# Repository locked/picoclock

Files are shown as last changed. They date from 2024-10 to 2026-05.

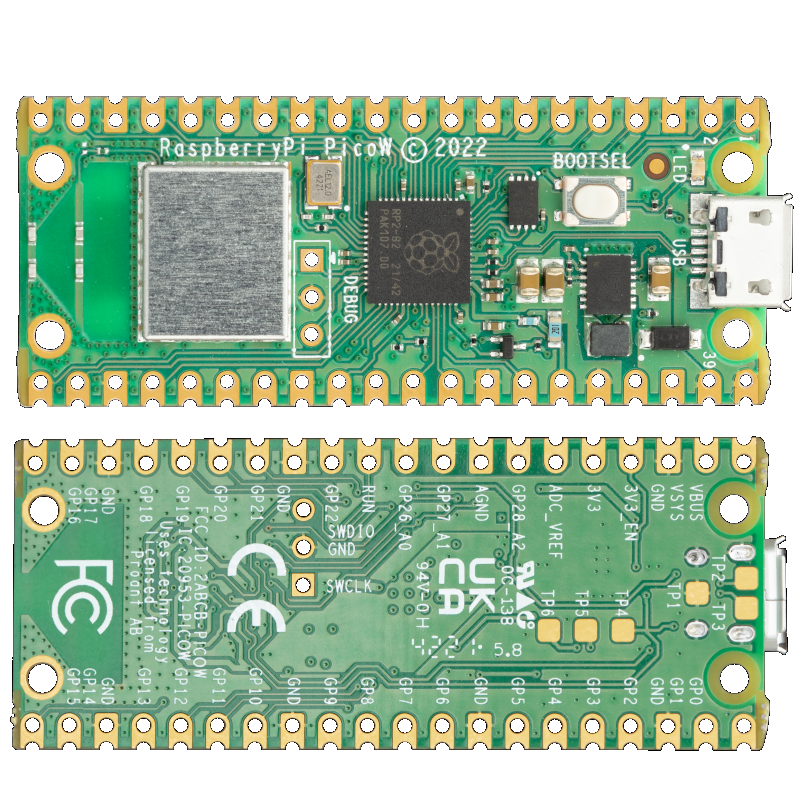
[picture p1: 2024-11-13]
pcb-mini/CYW43439/datasheets/raspberry-pi-pico-w.jpg

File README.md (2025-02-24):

# RP2040 based Alarm Clock

## Presentation

This repo is an attempt at building a Pico based alarm clock. It was created for my kids and features:

- date/time (obviously)
- alarm (plays wav file on sdcard)
- weather (current and forecast)
- epaper screen
- 3d printable case

The configuration is done remotely, and the clock synchronize from time to time (it can be forced too). The time is also fetched from a remote server.

## Repository Architecture

- **3d**: contains printable models for the case, buttons
- **fw**: the firmware, based on a lightweight "rtos"
- **pcb**: the PCBs:
  - the main PCB receiving the RP2040 board
  - the front PCB with the backlight leds
- **api**: remote api basic php script

## Pictures

case

## Build

```
mkdir build
cd build
cmake -DCMAKE_BUILD_TYPE=Debug ..
make
```

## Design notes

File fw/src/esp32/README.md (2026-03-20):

== building ==

Basic binary files are provided, but the code should be fairly easy to build with:

 arduino-cli compile -b esp32:esp32:esp32 --verbose

Then copy the binary from the build directory, for example:

 cp /home/user/.cache/arduino/sketches/XXX/esp32.ino.bin .

Once you have the 3 bin files (or just want to use the one from this repository), flash your module with esptool (change the `boot_app0.bin` path):

 esptool --chip esp32 --port "/dev/ttyUSB0" --baud 921600  --before default-reset --after hard-reset write-flash  -z --flash-mode keep --flash-freq keep --flash-size keep 0x1000 esp32.ino.bootloader.bin 0x8000 esp32.ino.partitions.bin 0xe000 path/to/esp32/tools/boot_app0.bin 0x10000 esp32.ino.bin

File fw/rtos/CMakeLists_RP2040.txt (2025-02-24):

cmake_minimum_required(VERSION 3.13)

set(CMAKE_VERBOSE_MAKEFILE OFF)
set(CMAKE_COLOR_MAKEFILE ON)
set(PROJECT_NAME picoclock)

set(PICO_BOARD pico_w)

# ==========================
# DEFAULT VARIABLES OPTIONS
# ==========================
if(NOT OST_BUNDLE)
    set(OST_BUNDLE "RASPI_PICO")
endif()

if(NOT PICO_SDK_PATH)
    set(PICO_SDK_PATH "../pico-sdk")
endif()

if(NOT CMAKE_BUILD_TYPE)
    set(CMAKE_BUILD_TYPE Release)
endif()

# ==========================
# COMMON FILES
# ==========================
set(OST_SRCS
    system/main.c
    system/alarms.c
    system/utils.c
    system/sdcard.c
    system/ff_diskio_sdcard.c
    system/debug.c
    system/filesystem.c
    system/sdcard.c
    system/qor.c
    system/qor_armv6m.s
    system/audio_player.c
    system/ui_task.c
    system/net_task.c
    system/fs_task.c
    system/audio_player.c
    system/ff/ff.c
    system/ff/ffsystem.c
    system/ff/ff_stubs.c
    library/mini_qoi.c
    library/tiny-json.c
    library/mcp9808/mcp9808.c
    library/pcf8563/pcf8563.c
    library/mcp46XX/mcp46XX.c
    library/mcp23009/mcp23009.c
    library/graphics.c
    library/tinyhttp/http.c
    library/tinyhttp/chunk.c
    library/tinyhttp/header.c
    #library/button_debounce.c
    library/flash_storage.c
    library/pico_i2s.c
    library/ini.c
    platform/raspberry-pico-w/wifi.c
    platform/raspberry-pico-w/pwm_sound.c
)
include_directories(
    ${CMAKE_CURRENT_SOURCE_DIR}/src
    ${CMAKE_CURRENT_SOURCE_DIR}/hal
    ${CMAKE_CURRENT_SOURCE_DIR}/include
    ${CMAKE_CURRENT_SOURCE_DIR}/library
    ${CMAKE_CURRENT_SOURCE_DIR}/system/ff
    ${CMAKE_CURRENT_SOURCE_DIR}/system/
    ${CMAKE_CURRENT_SOURCE_DIR}/library/epaper
    ${CMAKE_CURRENT_SOURCE_DIR}/library/epaper/Config
    ${CMAKE_CURRENT_SOURCE_DIR}/library/epaper/GUI
    ${CMAKE_CURRENT_SOURCE_DIR}/library/epaper/e-Paper
    ${CMAKE_CURRENT_SOURCE_DIR}/platform/raspberry-pico-w/
)

message("=============  TARGET: RASPBERRY PICO  =============")

add_definitions(-DOST_USE_FF_LIBRARY)

# initialize the SDK based on PICO_SDK_PATH
# note: this must happen before project()
include(${CMAKE_CURRENT_SOURCE_DIR}/platform/raspberry-pico-w/pico_sdk_import.cmake)

include(${CMAKE_CURRENT_SOURCE_DIR}/platform/raspberry-pico-w/pico_extras_import.cmake)

# add_library(BUNDLE_LIBRARIES INTERFACE)
# target_link_libraries(BUNDLE_LIBRARIES INTERFACE )
project(${PROJECT_NAME} LANGUAGES CXX C ASM)

set(CMAKE_VERBOSE_MAKEFILE OFF)
set(CMAKE_CXX_STANDARD 17)
set(CMAKE_CXX_STANDARD_REQUIRED ON)

# initialize the Raspberry Pi Pico SDK
# after project!
pico_sdk_init()

add_subdirectory(${CMAKE_CURRENT_SOURCE_DIR}/library/epaper/Config)
add_subdirectory(${CMAKE_CURRENT_SOURCE_DIR}/library/epaper/e-Paper)
add_subdirectory(${CMAKE_CURRENT_SOURCE_DIR}/library/epaper/Fonts)
add_subdirectory(${CMAKE_CURRENT_SOURCE_DIR}/library/epaper/GUI)

# ------ Executable
add_executable(${PROJECT_NAME} ${OST_SRCS} ${MIDDLEWARE_SRCS})

# ------ Link
target_link_libraries(${PROJECT_NAME} PUBLIC "-Wl,--start-group"
	gcc m c stdc++ pico_stdlib hardware_spi hardware_dma hardware_pio hardware_i2c hardware_rtc hardware_pwm hardware_exception cmsis_core pico_cyw43_arch_lwip_poll ePaper GUI Fonts Config pico_audio_i2s "-Wl,--end-group")
set_target_properties(${PROJECT_NAME} PROPERTIES OUTPUT_NAME "${PROJECT_NAME}")

pico_add_extra_outputs(${PROJECT_NAME})

pico_generate_pio_header(${PROJECT_NAME} ${CMAKE_CURRENT_LIST_DIR}/library/pico_i2s.pio)
#pico_generate_pio_header(${PROJECT_NAME} ${CMAKE_CURRENT_LIST_DIR}/library/button_debounce.pio)

pico_enable_stdio_usb(${PROJECT_NAME} 1)
pico_enable_stdio_uart(${PROJECT_NAME} 1)

target_compile_definitions(${PROJECT_NAME} PRIVATE
    WIFI_SSID=\"${WIFI_SSID}\"
    WIFI_PASSWORD=\"${WIFI_PASSWORD}\"
    SERVER_IP=\"${SERVER_IP}\"
    SERVER_PORT=\"${SERVER_PORT}\"
    PICO_AUDIO_I2S_MONO_INPUT=1
	#PICO_AUDIO_I2S_DATA_PIN=16
	#PICO_AUDIO_I2S_CLOCK_PIN_BASE=17
)

# ==========================
# CUSTOM TARGETS
# ==========================
add_custom_target(RaspberryPico
    COMMAND ${CMAKE_COMMAND}
    -DOST_BUNDLE=RASPI_PICO
    -DPICO_SDK_PATH=../pico-sdk
    -DPICO_BOARD=pico_w
    -DCMAKE_BUILD_TYPE=Debug
    -B "${CMAKE_CURRENT_BINARY_DIR}/RaspberryPico"
    -S "${CMAKE_SOURCE_DIR}"
    COMMAND ${CMAKE_COMMAND} --build "${CMAKE_CURRENT_BINARY_DIR}/RaspberryPico"
)

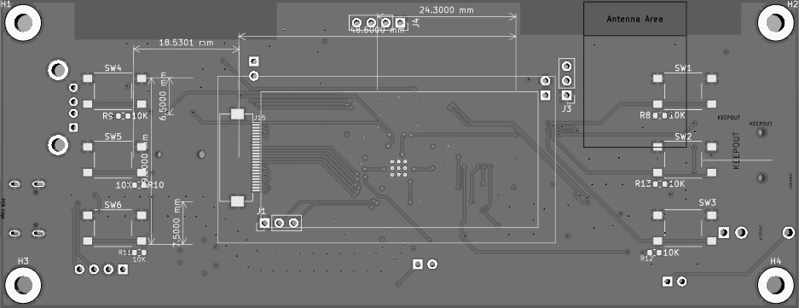
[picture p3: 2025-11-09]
3d-mini/picoclock.png

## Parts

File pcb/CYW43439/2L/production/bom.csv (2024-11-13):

Designator | Footprint | Quantity | Value | LCSC Part #
C1, C2 | 0603 | 2 | 18p | C1647
C10, C12, C7, C9 | 0603 | 4 | 1u | C15849
C11, C6, C8 | 0603 | 3 | 100n | C14663
C13, C14 | 0603 | 2 | 2.2u | C23630
C15, C16, C5 | 0603 | 3 | 4.7u | C19666
C17 | 0402 | 1 | 0.3p | C880415
C18 | 0402 | 1 | 0.36p
C19, C20 | 0402 | 2 | 0.2p | C2836760
C3, C4 | 0603 | 2 | 10p | C1634
FB1, FB2 | 0603 | 2 | 600@100MHz
J1 | PinHeader_1x03_P2.54mm_Vertical | 1 | GPIOs
J2 | PinHeader_1x04_P2.54mm_Vertical | 1 | SPI
J3 | PinHeader_1x02_P2.54mm_Vertical | 1 | Power
L1 | 0603 | 1 | 4.7n | C1030
L2 | 0603 | 1 | 2.2uH
R1 | 0603 | 1 | 220 | C22962
R2 | 0603 | 1 | 0
R3, R6 | 0603 | 2 | 10K | C25804
R4 | 0603 | 1 | 470 | C23179
R5 | 0603 | 1 | 22 | C23345
U1 | BGA63N40P7X12_287X487X55N | 1 | CYW43439KUBGT | C5359496
Y1 | Crystal_SMD_2016-4Pin_2.0x1.6mm | 1 | Crystal | C2901740

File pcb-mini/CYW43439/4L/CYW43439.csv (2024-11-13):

Id | Designator | Footprint | Quantity | Designation | Supplier and ref
1 | C13,C14 | C_0603_1608Metric | 2 | 2.2u
2 | C3,C4 | C_0603_1608Metric | 2 | 10p
3 | C20,C19 | C_0402_1005Metric | 2 | 0.2p
4 | J3 | PinHeader_1x02_P2.54mm_Vertical | 1 | Power
5 | FB1,FB2 | L_0603_1608Metric | 2 | 600@100MHz
6 | C6,C11,C8 | C_0603_1608Metric | 3 | 100n
7 | R6,R3 | R_0603_1608Metric | 2 | 10K
8 | C16,C15,C5 | C_0603_1608Metric | 3 | 4.7u
9 | C2,C1 | C_0603_1608Metric | 2 | 18p
10 | J2 | PinHeader_1x04_P2.54mm_Vertical | 1 | SPI
11 | L1 | L_0603_1608Metric | 1 | 4.7n
12 | C10,C12,C9,C7 | C_0603_1608Metric | 4 | 1u
13 | Y1 | Crystal_SMD_2016-4Pin_2.0x1.6mm | 1 | Crystal
14 | J1 | PinHeader_1x03_P2.54mm_Vertical | 1 | GPIOs
15 | R2 | R_0603_1608Metric | 1 | 0
16 | L2 | L_0603_1608Metric | 1 | 2.2u
17 | C17 | C_0402_1005Metric | 1 | 0.3p
18 | U1 | BGA63N40P7X12_287X487X55N | 1 | CYW43439KUBGT
19 | C18 | C_0402_1005Metric | 1 | 0.36p
20 | R4 | R_0603_1608Metric | 1 | 470
21 | R5 | R_0603_1608Metric | 1 | 22
22 | R1 | R_0603_1608Metric | 1 | 220

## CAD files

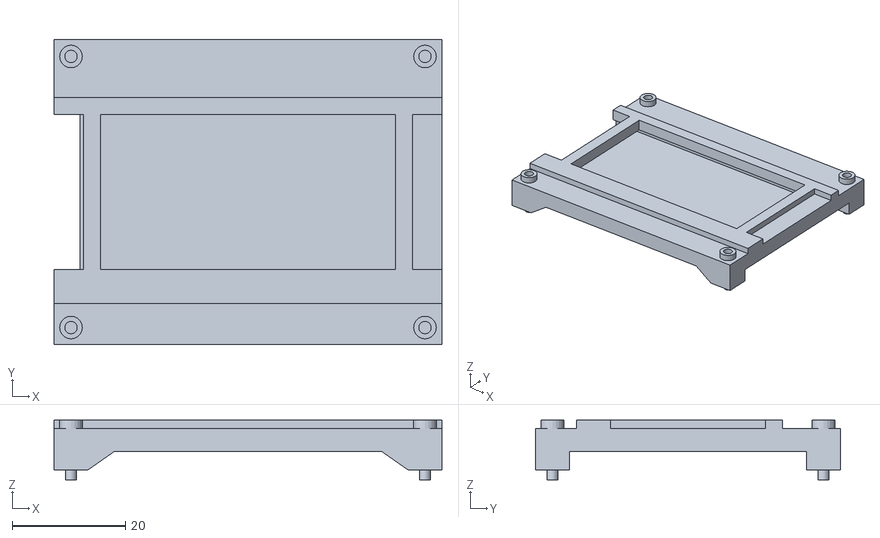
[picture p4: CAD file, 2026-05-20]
3d-mini/prod/v13/screen_holder-3.stl
68.4 x 53.8 x 10.5

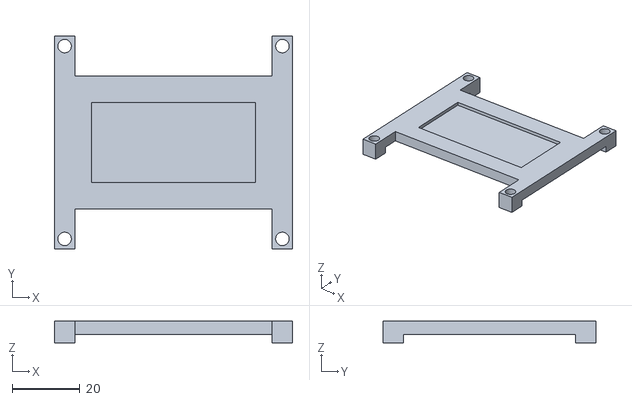
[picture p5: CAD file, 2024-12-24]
3d/front-v1/front.stl
70.4 x 63.0 x 6.50

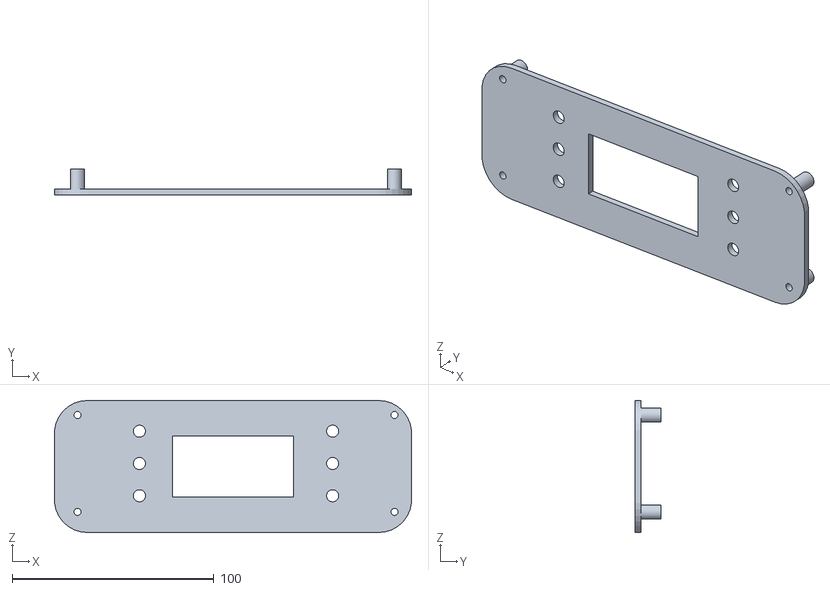
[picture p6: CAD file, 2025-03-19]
3d/panel-v1/panel.stl
176.8 x 13.0 x 65.4

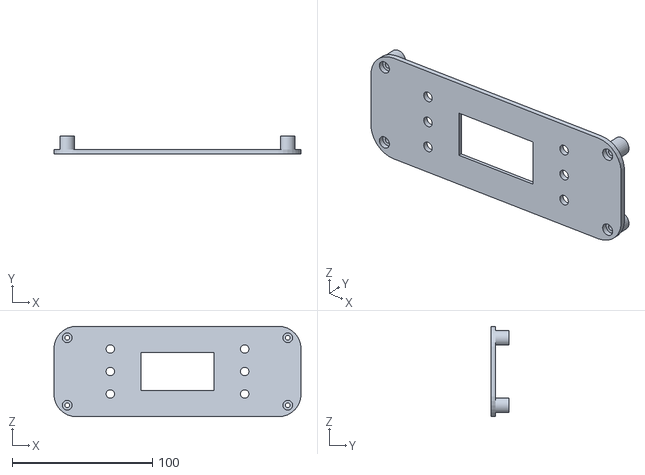
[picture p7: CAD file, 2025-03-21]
3d/panel.stl
175.8 x 12.5 x 64.4

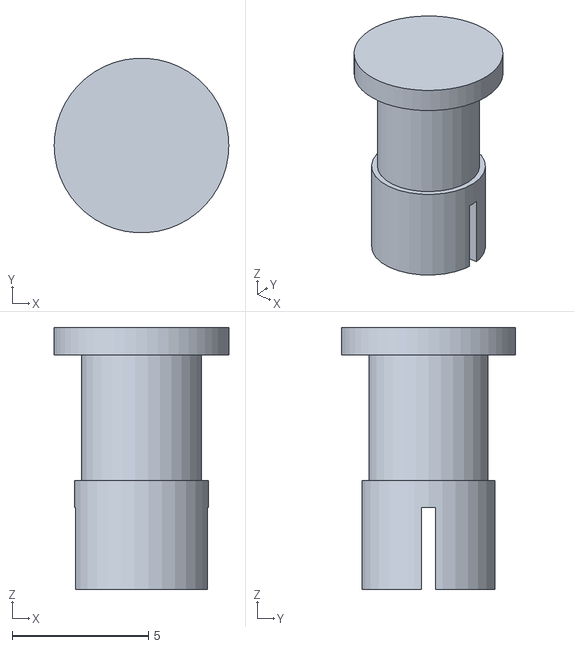
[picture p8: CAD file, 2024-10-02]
3d/prod1/button-2.4.stl
6.40 x 6.39 x 9.60

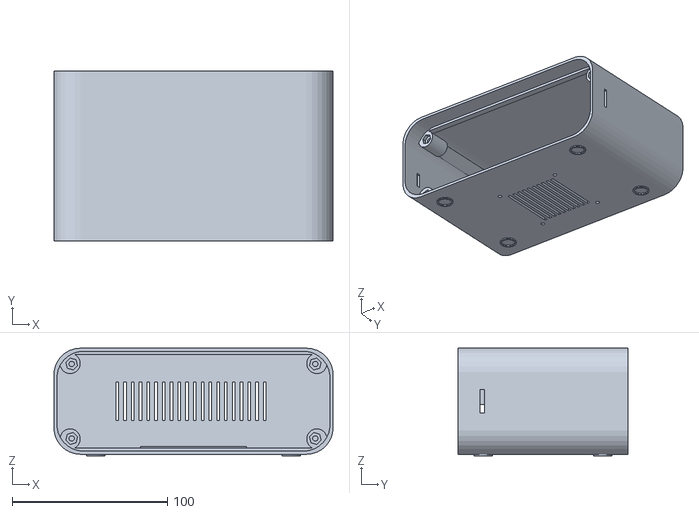
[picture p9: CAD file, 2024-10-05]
3d/prod2/case.stl
179.8 x 109.8 x 69.4

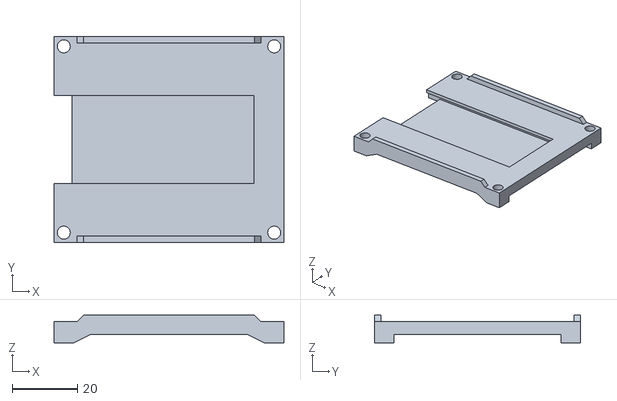
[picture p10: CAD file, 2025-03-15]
3d/front.stl
70.4 x 63.0 x 8.50

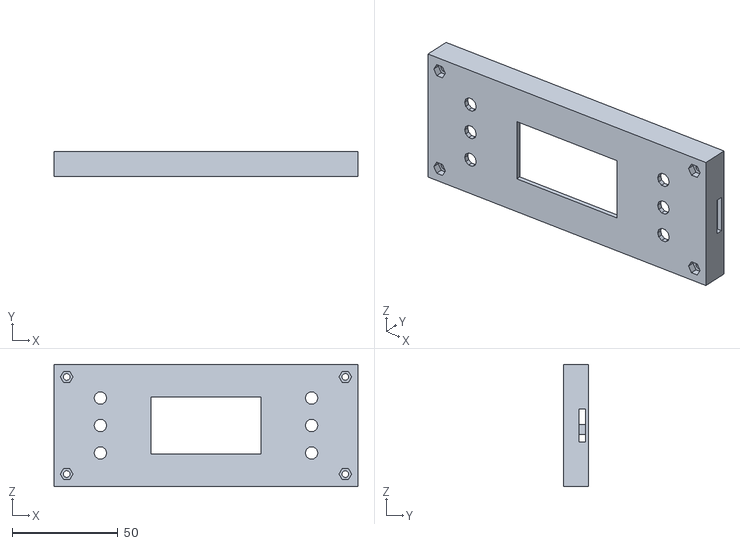
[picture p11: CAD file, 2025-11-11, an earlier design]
3d-mini/prod/v1/case-front.stl
144.0 x 12.0 x 58.0

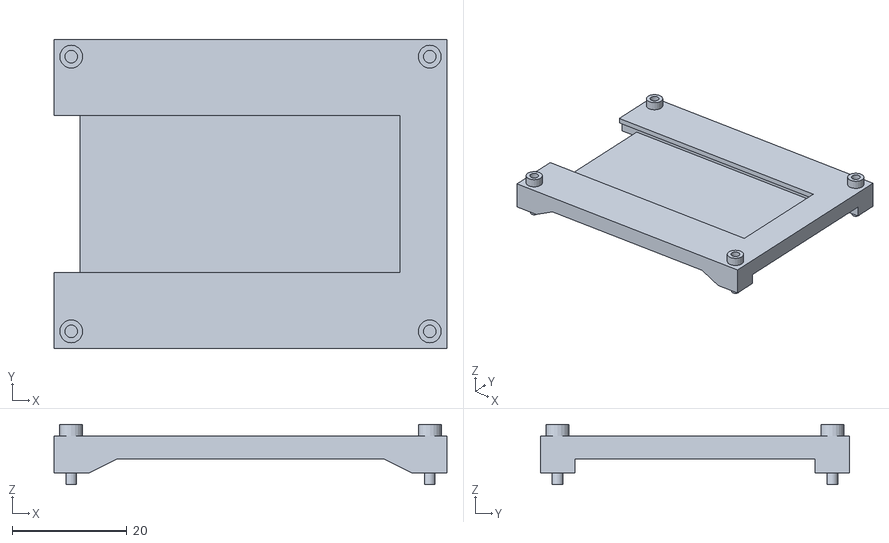
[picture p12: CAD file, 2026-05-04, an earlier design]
3d-mini/prod/v10/screen_holder.stl
68.4 x 53.8 x 10.5

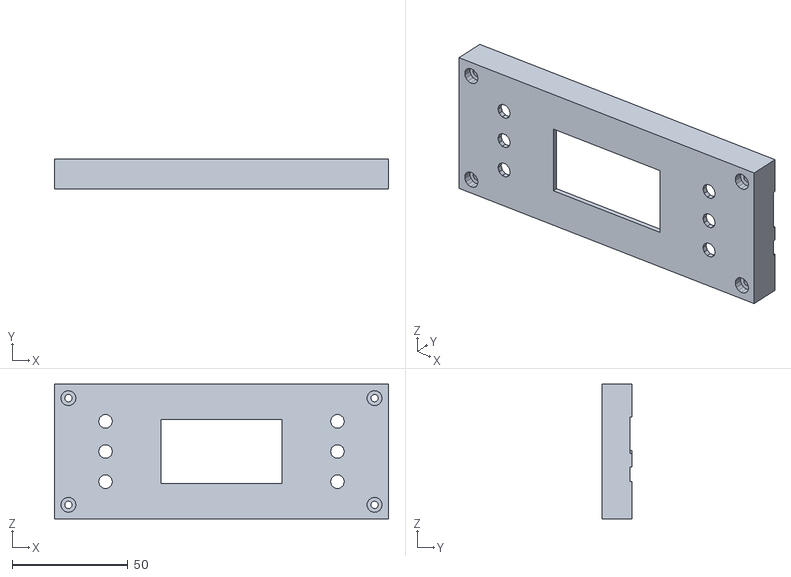
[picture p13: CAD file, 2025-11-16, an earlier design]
3d-mini/prod/v2/case-front.stl
144.0 x 13.0 x 58.0

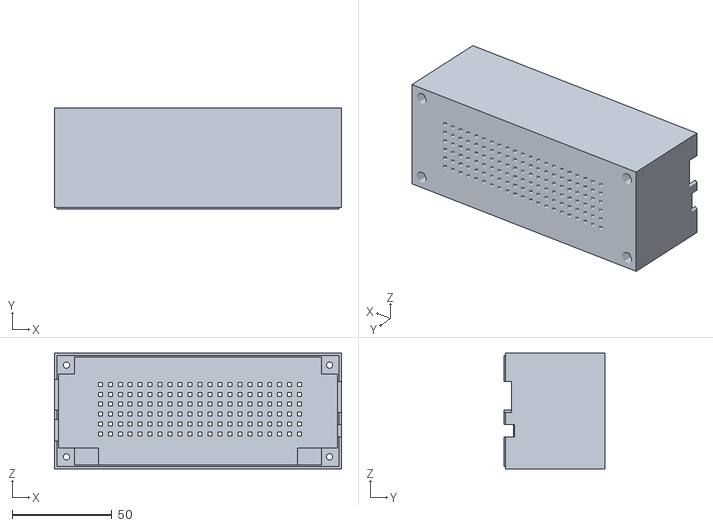
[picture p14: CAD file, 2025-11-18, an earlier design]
3d-mini/prod/v3/case-back.stl
144.0 x 50.8 x 58.0

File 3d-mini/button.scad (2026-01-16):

include <common.scad>;

hole_diam = 5.4;
outer_diam = 6;   // pcb holes are 5mm
inner_diam = 5;   // pcb holes are 5mm
depth = 6 + 1.6 + 1;
depth_blocker = 5.5 - 2.3;
depth_visible = 3.8;
sphere_visible = 0.4;

//btn_size = 2.4;	// Ok, tight
btn_size = 2.5;	// Ok, loose
btn = [btn_size, btn_size, 3];
fente = [1.4, 0.5, 3];

module body() {
    // part on btn
    cylinder(h=depth_blocker, d=inner_diam, $fn=30);
    // blocker
    translate([0, 0, depth_blocker-1]) cylinder(h=1, d=outer_diam+2, $fn=50);
    // visible part
    minkowski()
    {
        translate([0, 0, depth_blocker]) cylinder(h=depth_visible-sphere_visible, d=hole_diam-0.4-sphere_visible*2, $fn=40);
        sphere(sphere_visible);
    }
}

difference() {
    body();

    shiftx = 0.1;

    translate([0-shiftx, 0, btn[2]/2]) cube(btn, center=true);
    translate([-btn[0]/2-fente[0]/2-shiftx, 0, fente[2]/2]) cube(fente, center=true);
    translate([+btn[0]/2+fente[0]/2-shiftx, 0, fente[2]/2]) cube(fente, center=true);
}

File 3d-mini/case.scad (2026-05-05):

include <common.scad>;
include <screen_holder.scad>;

support_large_speaker = true;

module pcb() {
    rotate([90]) translate([t, t]) difference() {
        cube(pcb);
        for (x = [0:1]) {
            for (y = [0:1]) {
                translate([pcb_screw_pos[0] + x * (pcb[0]-pcb_screw_pos[0]*2), pcb_screw_pos[0] + y * (pcb[1]-pcb_screw_pos[1]*2)]) cylinder(pcb[2], pcb_screw_diam/2, pcb_screw_diam/2, $fn=15);
            }
        }

        // Pins holes
        for (x = [0:1]) {
            for (y = [0:1]) {
                cyl_x = (x == 0 ? 1 : -1) * screen_holder_in[0]/2 + (x == 0 ? -1 : 1) * screen_holder_out[0]/2;
                cyl_y = (y == 0 ? 1 : -1) * screen_holder_out[1]/2 + (y == 0 ? -1 : 1) * screen_holder_screw_rad + (y == 0 ? -1 : 1) * 1;
                echo(cyl_x, cyl_y);
                translate([
                    cyl_x - t,
                    cyl_y - t,
                    -15])
                translate([front[0]/2, front[1]/2, front[2]+2.7])
                cylinder(h=3, d=2.5, $fn=20);
            }
        }
    }

    rotate([90]) io();
}

module front_screw() {
    // PCB support screw
    for (x = [0:1]) {
        for (y = [0:1]) {
            translate([
                (x == 0 ? pcb[0] - pcb_screw_pos[0] : pcb_screw_pos[0]) + t,
                (y == 0 ? pcb[1] - pcb_screw_pos[1] : pcb_screw_pos[1]) + t,
                0
            ]) cylinder(front[2], pcb_screw_diam/2, pcb_screw_diam/2, $fn=15);

            translate([
                (x == 0 ? pcb[0] - pcb_screw_pos[0] : pcb_screw_pos[0]) + t,
                (y == 0 ? pcb[1] - pcb_screw_pos[1] : pcb_screw_pos[1]) + t,
                front[2] - pcb_bolt_depth]) cylinder(h=pcb_bolt_depth, r=pcb_bolt_diam/2, $fn=15);
        }
    }
}
module front_joint(joint_width_margin=0, y_adjust=0) {
    for (i = [0:1]) {
        // horizontal
        translate([
            t/2 + joint_margin,
            i * front[1] + (i == 0 ? 1 : -2) * joint_width + (i == 0 ? 1 : -1) * joint_margin + (i == 0 ? 0 : -1) * joint_width_margin,
            -1+joint_margin + y_adjust]) cube([
                front[0]-t-joint_margin*2,
                joint_width+joint_width_margin,
                1-joint_margin
            ]);
    }
    for (i = [0:1]) {
        // vertical
        translate([
            i * front[0] + (i == 0 ? 1 : -2) * joint_width + (i == 0 ? 1 : -1) * joint_margin + (i == 0 ? 0 : -1) * joint_width_margin,
            t/2 + joint_margin,
            -1+joint_margin + y_adjust]) cube([
                joint_width+joint_width_margin,
                front[1]-t-joint_margin*2,
                1-joint_margin
            ]);
    }
}
module back_joint() {
    for (i = [0:1]) {
        translate([
            0,
            i * front[1] + (i == 0 ? 0 : -1) * joint_width + (i == 0 ? 0 : 0) * joint_margin,
            0]) cube([
                front[0],
                joint_width,
                1
            ]);
    }
    for (i = [0:1]) {
        translate([
            i * front[0] + (i == 0 ? 0 : -1) * joint_width + (i == 0 ? 0 : 0) * joint_margin,
            0,
            0]) cube([
                joint_width,
                front[1],
                1
            ]);
    }
}
module front() {
    front_inner = [pcb[0] + pcb_margin, pcb[1] + pcb_margin, front[2] - t];

    rotate([90]) difference() {
        union(){
            cube(front);
            front_joint();
        }
        translate([t-pcb_margin/2, t-pcb_margin/2]) cube(front_inner);
        front_screw();
        screen();
        buttons();
        io();
        borders();
        cornersfront();
        bordersfront();
    }

    // screen holder pins
    rotate([90]) translate([
        front[0]/2,
        front[1]/2,
        front[2]-t
    ]) screen_holder_pins();
    // screen stop pin
    rotate([90]) translate([
        front[0]/2 - screen_holder_out[1]/2 - 8.3,
        16,
        front[2]-t-5])
    cube([3,3,5]);

    // add PCB support (cannot do it earlier
    // since it overlap with main body and
    // difference does not handle that well)
    rotate([90]) difference() {
        for (x = [0:1]) {
            for (y = [0:1]) {
                translate([
                    t + x * (front[0] - pcb_support[0] - t*2) + (x == 1 ? 1 : -1) * pcb_margin / 2,
                    t + y * (front[1] - pcb_support[1] - t*2) + (y == 1 ? 1 : -1) * pcb_margin / 2,
                    pcb[2]]) cube(pcb_support);
            }
        }
        front_screw();
    }
}

module io(forback=false) {
    // usb-c
    translate([
        0,
        front[1]/2 - usbc_pos - usbc[1] / 2,
        -usbc[0],
    ]) cube([usbc[2], usbc[1], usbc[0] + (forback ? 1 : 0)]);

    // usb-a
    translate([
        0,
        front[1]/2 + usba_pos - usba[1] / 2,
        -usba[0],
    ]) cube([usba[2], usba[1], usba[0] + (forback ? 1 : 0)]);

    // SD card
    translate([
        front[0] - sd[2],
        front[1]/2 + sd_pos - sd[1]/2,
        -sd[0],
    ]) cube([sd[2], sd[1], sd[0] + (forback ? 1 : 0)]);

    // Jack
    translate([
        front[0] - jack[2],
        front[1]/2 - jack_pos - jack[1]/2,
        -jack[0],
    ]) cube([jack[2], jack[1], jack[0] + (forback ? 1 : 0)]);
}

module screen() {
    translate([
        front[0]/2 - screen_visible_size[0]/2,
        front[1]/2 - screen_visible_size[1]/2,
        front[2]-t,
    ]) cube([
        screen_visible_size[0],
        screen_visible_size[1],
        screen_visible_size[2]
    ]);
}

module buttons() {
    for (i=[0:6]) {
        x = (i < 3 ? 1 : -1) * button_x;
        y = (i % 3) * button_y - button_y;
        translate([front[0]/2 + x, front[1]/2 + y, front[2] - t]) cylinder(h=t, d=button_radius*2);
    }
}

module screen_holder_pins() {
    // Pins toward PCB
    pin_height = 1.6;
    for (x = [0:1])  {
        for (y = [0:1]) {
            cyl_x = (x == 0 ? 1 : -1) * screen_holder_in[0]/2 + (x == 0 ? -1 : 1) * screen_holder_out[0]/2;
            cyl_y = (y == 0 ? 1 : -1) * screen_holder_out[1]/2 + (y == 0 ? -1 : 1) * screen_holder_screw_rad + (y == 0 ? -1 : 1) * 1;
            //echo(cyl_x, cyl_y);
            translate([
                cyl_x,
                cyl_y,
                -pin_height])
            cylinder(h=pin_height, d1=1.8, d2=2, $fn=20);
        }
    }
}



module inserts_holes() {
    // inserts
    for (x = [0:1]) {
        for (y = [0:1]) {
            translate([
                (x == 0 ? pcb[0] - pcb_screw_pos[0] : pcb_screw_pos[0]) + t,
                (y == 0 ? pcb[1] - pcb_screw_pos[1] : pcb_screw_pos[1]) + t,
                -30-5+0.8])
            cylinder(h=30, r=pcb_screw_diam/2+0.1, $fn=15);

            translate([
                (x == 0 ? pcb[0] - pcb_screw_pos[0] : pcb_screw_pos[0]) + t,
                (y == 0 ? pcb[1] - pcb_screw_pos[1] : pcb_screw_pos[1]) + t,
                -5+0.8])
            cylinder(h=5, r=2.5, $fn=15);
        }
    }
}
module back_screw() {
    // PCB support screw
    for (x = [0:1]) {
        for (y = [0:1]) {
            translate([
                (x == 0 ? pcb[0] - pcb_screw_pos[0] : pcb_screw_pos[0]) + t,
                (y == 0 ? pcb[1] - pcb_screw_pos[1] : pcb_screw_pos[1]) + t,
                -back[2]-t])
            cylinder(h=back[2]+t+1, r=pcb_screw_diam/2, $fn=15);

            // bolt
            translate([
                (x == 0 ? pcb[0] - pcb_screw_pos[0] : pcb_screw_pos[0]) + t,
                (y == 0 ? pcb[1] - pcb_screw_pos[1] : pcb_screw_pos[1]) + t,
                -back[2] - pcb_bolt_depth])
            cylinder(h=pcb_bolt_back_depth, r=pcb_bolt_diam/2, $fn=6);
        }
    }
}
module speaker2_holes() {
    for (x = [0:1]) {
        for (y = [0:1]) {
            translate([
                (x == 0 ? -1 : 1) * speaker2_screw_from_center,
                (y == 0 ? -1 : 1) * speaker2_screw_from_center,
                -t-speaker2_support[2]
            ]) cylinder(h=10, r=1.6, $fn=10);
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

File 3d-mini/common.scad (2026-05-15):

// PCB size
pcb = [140, 54, 1.6];
pcb_screw_diam = 3.6;
pcb_screw_pos = [4, 4];
pcb_bolt_diam = 6.5;
pcb_bolt_depth = 3.2;
pcb_bolt_length = 30;
pcb_image = "picoclock_scaled.png";
pcb_margin = 0.4;

// general thickness
t = 1.5;

front = [pcb[0] + t * 2, pcb[1] + t * 2, 12];
back = [pcb[0] + t * 2, pcb[1] + t * 2, 60];
pcb_bolt_back_depth = back[2] - pcb_bolt_length + t + pcb_bolt_depth + front[2];

pcb_support = [pcb_screw_pos[0]*2+pcb_margin/2, pcb_screw_pos[0]*2+pcb_margin/2, front[2] - pcb[2] - t];

joint_margin = 0.2;
joint_width = t/2 - joint_margin;

screen_size = [59.3, 29.6, 1.5];
screen_visible_size = [52, 27.4, 3];

button_x = 50;
button_y = 13;
button_radius = 3;

usbc = [3, 10.7, 10.3];
usba = [6, 15.5, 16.3];
sd = [1.6, 15.7, 19.7];
jack = [4.5, 6.3, 14];
usbc_pos = 9.6;  // from center
usba_pos = 8.14; // from center
sd_pos = 7;
jack_pos = 9.85;

speaker_plate = [132, 10, 19];
speaker = [100, 36, 28];
speaker_support = [11, pcb_support[1], 22];

speaker2 = [51.5, 19.5, 30.3];
speaker2_baffle_diam = 47;
speaker2_screw_diam = 60;
speaker2_screw_from_center = speaker2_screw_diam / 2 * sqrt(2) / 2;
speaker2_support = [52, 52, 2];

screen_holder_screw_rad = 2;
screen_holder_out = [screen_holder_screw_rad*3, pcb[1] - 0.2, 3.5];
//screen_holder_in = [70.4, 39.2, 4];
screen_holder_in = [68.4, 39.2, 4];
screen_size_toborder = 7.1;


// pin position:
// 32.2 / 24
// center: 144 / 2, 58 / 2
// => 72 +/- 31.2 => 40.8 / 103.2
// => 29 +- 24 => 5 / 53
// +80:
// 120.8 / 183.2
// 85 / 133

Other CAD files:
3d-mini/prod/v13/screen_holder.stl
3d/button.stl
3d/prod1/button-2.5.stl
3d/prod1/case_v2.stl
3d/prod1/button-2.3.stl
3d-mini/prod/v11/screen_holder.stl
3d-mini/prod/v12/screen_holder.stl
3d-mini/button_shortbase.scad
3d-mini/prod/v1/case-pcb.stl
3d-mini/prod/v1/case-screenholder.stl
3d-mini/prod/v10/button_shortbase.stl
3d-mini/prod/v10/case-front.stl
3d-mini/prod/v10/case.stl
3d-mini/prod/v11/case-back.stl
3d-mini/prod/v2/case-back.stl
3d-mini/prod/v2/case-screenholder.stl
3d-mini/prod/v2/pcb.stl
3d-mini/prod/v3/case-front.stl
3d-mini/prod/v3/pcb.stl
3d-mini/prod/v3/screenholder.stl
3d-mini/prod/v4/case-back.stl
3d-mini/prod/v5/case-back.stl
3d-mini/prod/v5/case-front.stl
3d-mini/prod/v6/case-back.stl
3d-mini/prod/v6/case-front.stl
3d-mini/prod/v7/button.stl
3d-mini/prod/v7/case-back.stl
3d-mini/prod/v7/case-front.stl
3d-mini/prod/v8/case-back.stl
3d-mini/prod/v9/button.stl
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

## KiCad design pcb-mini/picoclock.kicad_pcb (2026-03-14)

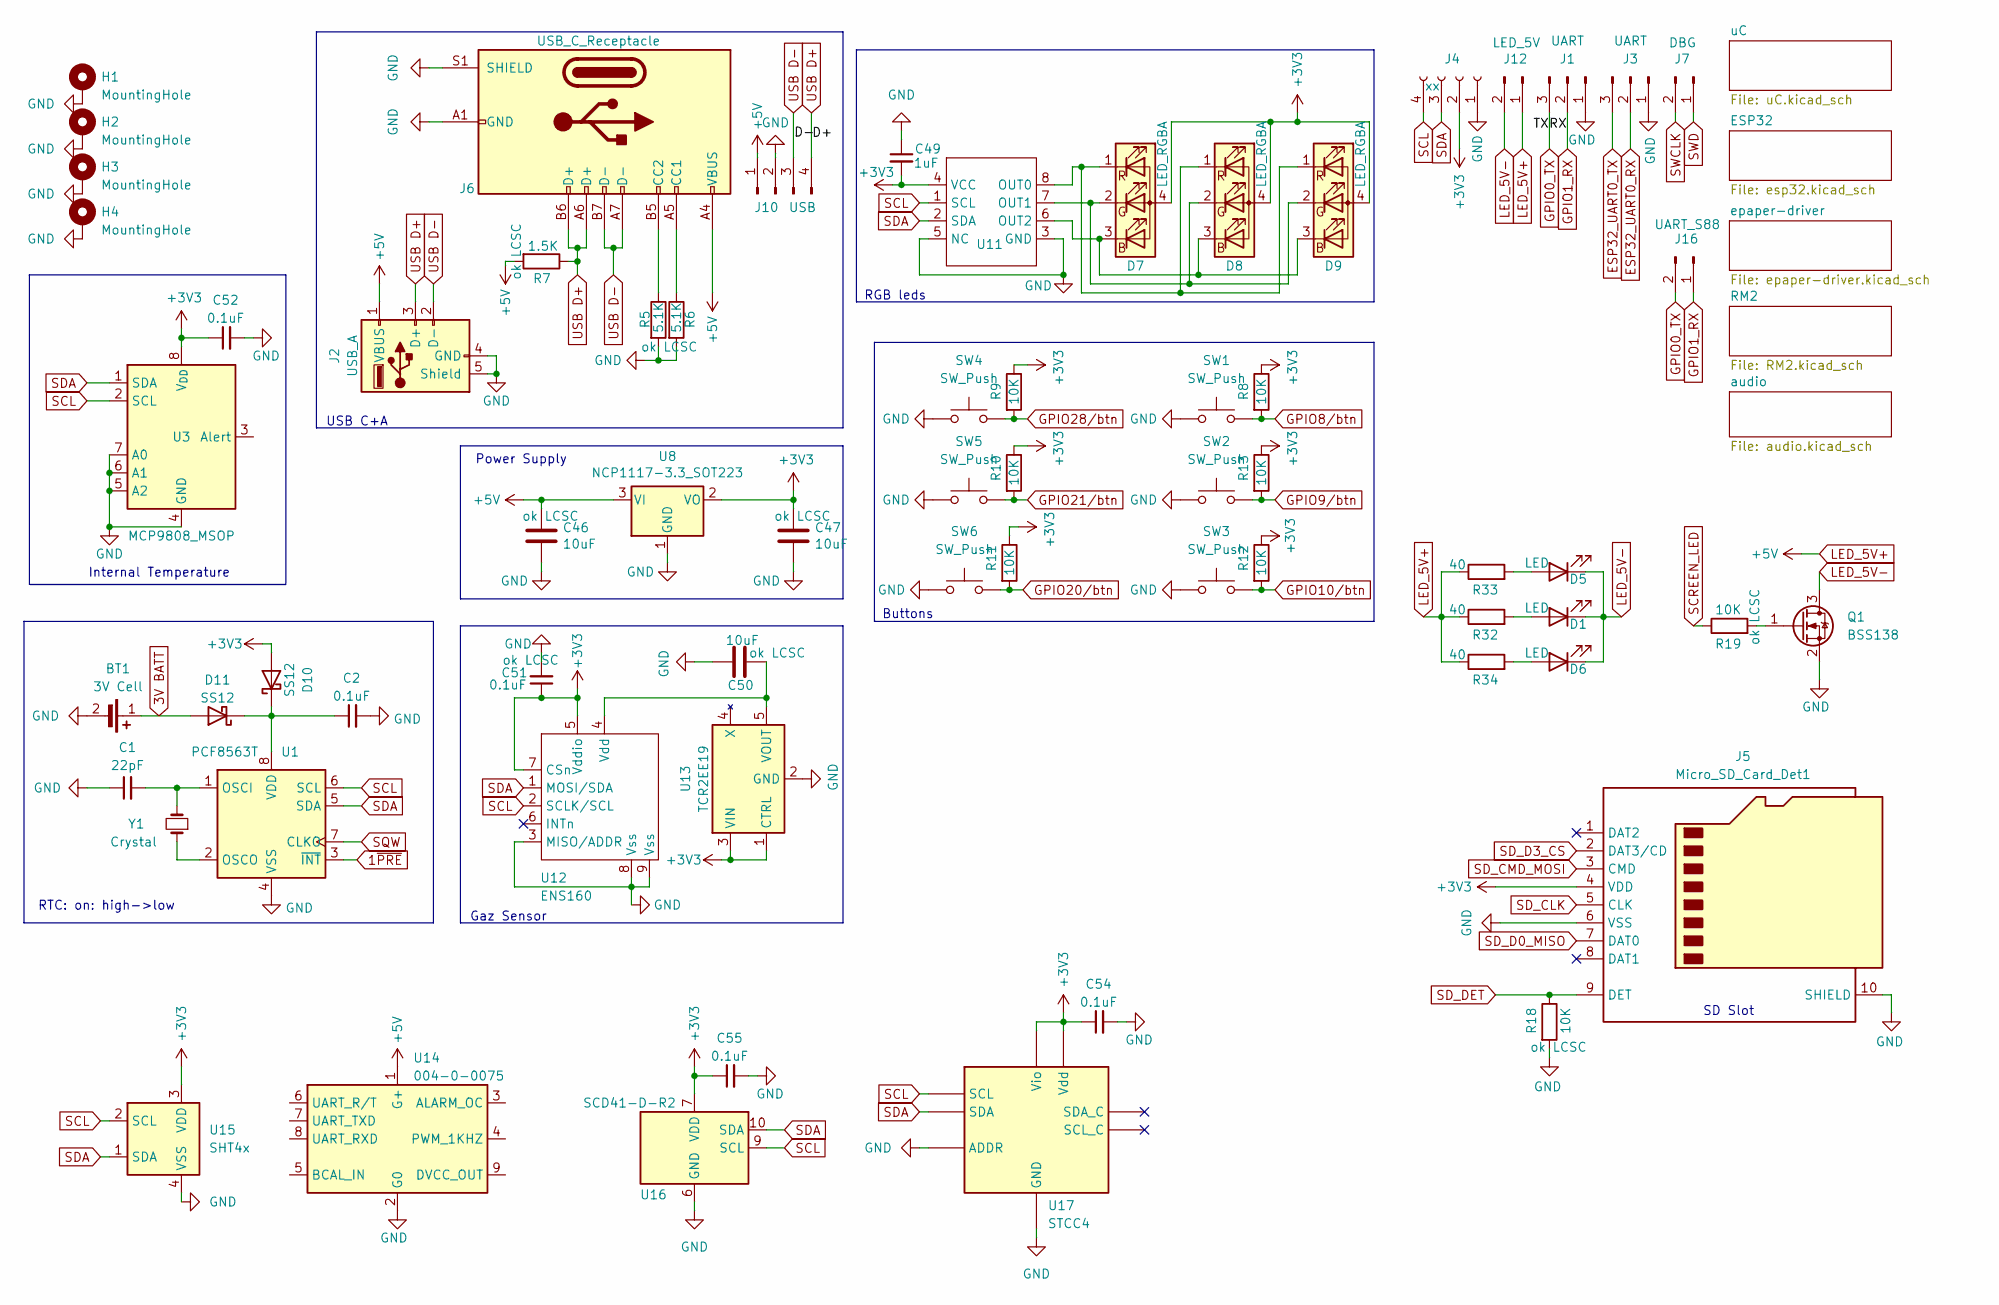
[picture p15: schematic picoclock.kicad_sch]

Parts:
BT1: 3V Cell; MPD_BC501SM-TR
C1: 22pF; C_0603_1608Metric; LCSC C1653
C2, C51, C52, C54, C55: 0.1uF; C_0603_1608Metric; LCSC C14663
C46, C47, C50: 10uF; C_0805_2012Metric; LCSC C15850
C49: 1uF; C_0603_1608Metric
D1, D5, D6: LED; LED_PLCC_2835
D7, D8, D9: LED_RGBA; LED_LiteOn_LTST-C19HE1WT
D10, D11: SS12; D_SOD-323
H1, H2, H3, H4: MountingHole; MountingHole_3.2mm_M3_Pad
J1, J3: UART; PinHeader_1x03_P2.54mm_Vertical
J2: USB_A; USB_A_Connfly_DS1095
J4: xx; PinSocket_1x04_P2.54mm_Vertical
J5: Micro_SD_Card_Det1; microSD_HC_Hirose_DM3AT-SF-PEJM5_combined_MSD-4-A
J6: USB_C_Receptacle; USB_C_Receptacle_GCT_USB4105-xx-A_16P_TopMnt_Horizontal
J7: DBG; PinHeader_1x02_P2.54mm_Vertical
J10: USB; PinHeader_1x04_P2.54mm_Vertical
J12: LED_5V; PinHeader_1x02_P2.54mm_Vertical
J16: UART_S88; PinHeader_1x02_P2.54mm_Vertical
Q1: BSS138; SOT-23-3
R5, R6: 5.1K; R_0603_1608Metric; LCSC C23186
R7: 1.5K; R_0603_1608Metric; LCSC C22843
R8, R9, R10, R11, R12, R13: 10K; R_0603_1608Metric; LCSC C25744
R18, R19: 10K; R_0402_1005Metric; LCSC C25744
R32, R33, R34: 40; R_0603_1608Metric
SW1, SW2, SW3, SW4, SW5, SW6: SW_Push; SW_SPST_TL3301TG
U1: PCF8563T; SOIC-8_3.9x4.9mm_P1.27mm; LCSC C7440
U3: MCP9808_MSOP; MSOP-8_3x3mm_P0.65mm; LCSC C129490
U8: NCP1117-3.3_SOT223; SOT-223-3_TabPin2
U11: LP5817
U12: ENS160
U13: TCR2EE19; SC-74A-5_1.55x2.9mm_P0.95mm
U14: 004-0-0075
U15: SHT4x; Sensirion_DFN-4_1.5x1.5mm_P0.8mm_SHT4x_NoCentralPad
U16: SCD41-D-R2; Sensirion_SCD4x-1EP_10.1x10.1mm_P1.25mm_EP4.8x4.8mm
U17: STCC4; LCSC C49191471
Y1: Crystal; Crystal_SMD_3215-2Pin_3.2x1.5mm; LCSC C32346

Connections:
1~PRE: U1.3 (~INT); also elsewhere on the board
3V BATT: BT1.1 (+), D11.2 (A)
+3V3: C47.1, C49.2, C51.1, C52.1, C54.1, C55.1, D7.4 (A), D8.4 (A), D9.4 (A), D10.2 (A), J4.2, J5.4 (VDD), R8.1, R9.1, R10.1, R11.1, R12.1, R13.1, U3.8 (V_{DD}), U8.2 (VO), U11.4 (VCC), U12.5 (Vddio), U12.7 (CSn), U13.1 (CTRL), U13.3 (VIN), U15.3 (VDD), U16.7 (VDD), U16.19 (VDD), U17.6 (Vio), U17.7 (Vdd); also elsewhere on the board
ESP32_UART0_RX: J3.2; also elsewhere on the board
ESP32_UART0_TX: J3.3; also elsewhere on the board
GND: BT1.2 (-), C1.1, C2.2, C46.2, C47.2, C49.1, C50.2, C51.2, C52.2, C54.2, C55.2, H1.1, H2.1, H3.1, H4.1, J1.1, J2.4 (GND), J2.5 (Shield), J3.1, J4.1, J5.6 (VSS), J5.10 (SHIELD), J6.A1 (GND), J6.A12 (GND), J6.B1 (GND), J6.B12 (GND), J6.S1 (SHIELD), J10.2, Q1.2 (S), R5.2, R6.2, R18.2, SW1.1, SW2.1, SW3.1, SW4.1, SW5.1, SW6.1, U1.4 (VSS), U3.4 (GND), U3.5 (A2), U3.6 (A1), U3.7 (A0), U8.1 (GND), U11.3 (GND), U11.5 (NC), U12.3 (MISO/ADDR), U12.8 (Vss), U12.9 (Vss), U13.2 (GND), U14.2 (G0), U15.4 (VSS), U16.6 (GND), U16.20 (GND), U16.21 (GND), U17.3 (ADDR), U17.4 (GND); also elsewhere on the board
GPIO0_TX: J1.3, J16.2; also elsewhere on the board
GPIO1_RX: J1.2, J16.1; also elsewhere on the board
GPIO8/btn: R8.2, SW1.2; also elsewhere on the board
GPIO9/btn: R13.2, SW2.2; also elsewhere on the board
GPIO10/btn: R12.2, SW3.2; also elsewhere on the board
GPIO20/btn: R11.2, SW6.2; also elsewhere on the board
GPIO21/btn: R10.2, SW5.2; also elsewhere on the board
GPIO28/btn: R9.2, SW4.2; also elsewhere on the board
LED_5V+: C46.1, J2.1 (VBUS), J6.A4 (VBUS), J6.A9 (VBUS), J6.B4 (VBUS), J6.B9 (VBUS), J10.1, J12.1, R7.2, R32.1, R33.1, R34.1, U8.3 (VI), U14.1 (G+)
LED_5V-: D1.1 (K), D5.1 (K), D6.1 (K), J12.2, Q1.3 (D)
unnamed: D1.2 (A), R32.2
unnamed: D5.2 (A), R33.2
unnamed: D6.2 (A), R34.2
unnamed: D7.3 (BK), D8.3 (BK), D9.3 (BK), U11.6 (OUT2)
unnamed: D7.2 (GK), D8.2 (GK), D9.2 (GK), U11.7 (OUT1)
unnamed: D7.1 (RK), D8.1 (RK), D9.1 (RK), U11.8 (OUT0)
unnamed: C2.1, D10.1 (K), D11.1 (K), U1.8 (VDD)
unnamed: J6.A5 (CC1), R6.1
unnamed: J6.B5 (CC2), R5.1
unnamed: Q1.1 (G), R19.2
unnamed: C1.2, U1.1 (OSCI), Y1.2
unnamed: U1.2 (OSCO), Y1.1
unnamed: C50.1, U12.4 (Vdd), U13.5 (VOUT)
SCL: J4.4, U1.6 (SCL), U3.2 (SCL), U11.1 (SCL), U12.2 (SCLK/SCL), U15.2 (SCL), U16.9 (SCL), U17.1 (SCL); also elsewhere on the board
SCREEN_LED: R19.1; also elsewhere on the board
SDA: J4.3, U1.5 (SDA), U3.1 (SDA), U11.2 (SDA), U12.1 (MOSI/SDA), U15.1 (SDA), U16.10 (SDA), U17.5 (SDA); also elsewhere on the board
SD_CLK: J5.5 (CLK); also elsewhere on the board
SD_CMD_MOSI: J5.3 (CMD); also elsewhere on the board
SD_D0_MISO: J5.7 (DAT0); also elsewhere on the board
SD_D3_CS: J5.2 (DAT3/CD); also elsewhere on the board
SD_DET: J5.9 (DET), R18.1; also elsewhere on the board
SQW: U1.7 (CLKO); also elsewhere on the board
SWCLK: J7.2; also elsewhere on the board
SWD: J7.1; also elsewhere on the board
USB D+: J2.3 (D+), J6.A6 (D+), J6.B6 (D+), J10.4, R7.1; also elsewhere on the board
USB D-: J2.2 (D-), J6.A7 (D-), J6.B7 (D-), J10.3; also elsewhere on the board

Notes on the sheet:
USB C+A
SD Slot
Internal Temperature
RTC: on: high->low
Power Supply
RGB leds
Buttons
Gaz Sensor

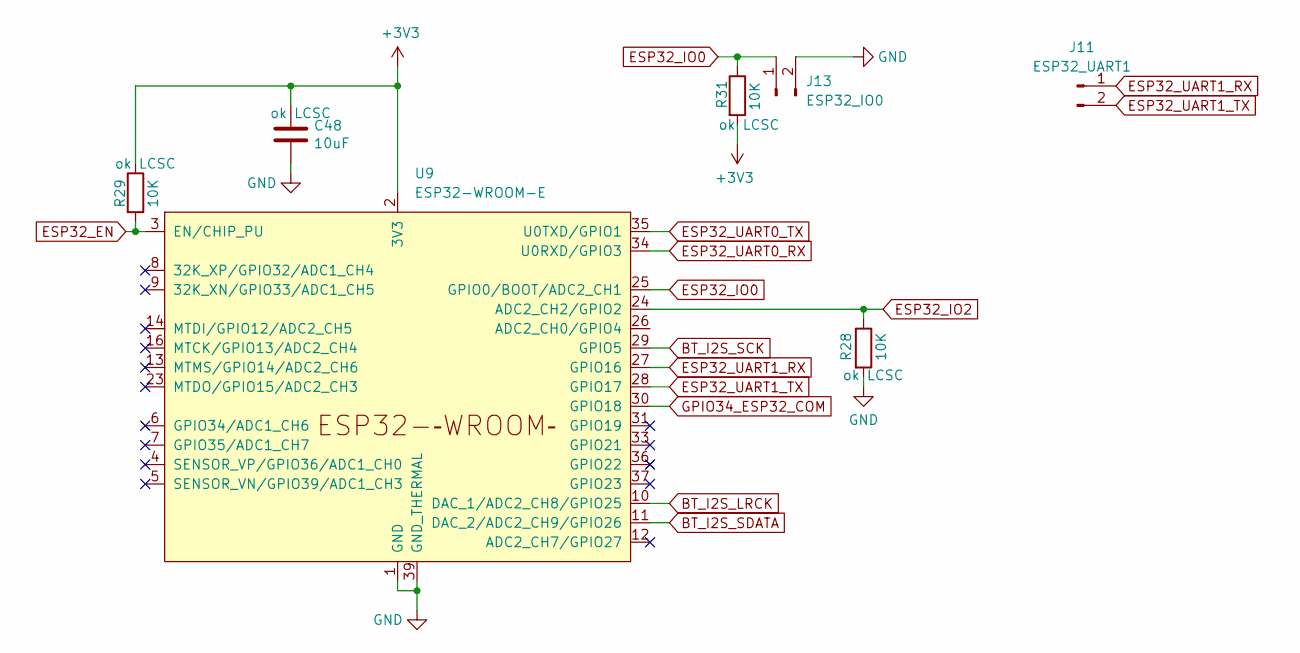
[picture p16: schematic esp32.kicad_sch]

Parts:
C48: 10uF; C_0805_2012Metric; LCSC C15850
J11: ESP32_UART1; PinHeader_1x02_P2.54mm_Vertical
J13: ESP32_IO0; PinHeader_1x02_P2.54mm_Vertical
R28, R29, R31: 10K; R_0402_1005Metric; LCSC C25744
U9: ESP32-WROOM-E; ESP32-WROOM-32E

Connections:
+3V3: C48.1, R29.1, R31.2, U9.2 (3V3); also elsewhere on the board
BT_I2S_LRCK: U9.10 (DAC_1/ADC2_CH8/GPIO25); also elsewhere on the board
BT_I2S_SCK: U9.29 (GPIO5); also elsewhere on the board
BT_I2S_SDATA: U9.11 (DAC_2/ADC2_CH9/GPIO26); also elsewhere on the board
ESP32_EN: R29.2, U9.3 (EN/CHIP_PU)
ESP32_IO0: J13.1, R31.1, U9.25 (GPIO0/BOOT/ADC2_CH1)
ESP32_IO2: R28.1, U9.24 (ADC2_CH2/GPIO2)
ESP32_UART0_RX: U9.34 (U0RXD/GPIO3); also elsewhere on the board
ESP32_UART0_TX: U9.35 (U0TXD/GPIO1); also elsewhere on the board
ESP32_UART1_RX: J11.1, U9.27 (GPIO16); also elsewhere on the board
ESP32_UART1_TX: J11.2, U9.28 (GPIO17); also elsewhere on the board
GND: C48.2, J13.2, R28.2, U9.1 (GND), U9.15 (GND), U9.38 (GND), U9.39 (GND_THERMAL); also elsewhere on the board
GPIO34_ESP32_COM: U9.30 (GPIO18); also elsewhere on the board

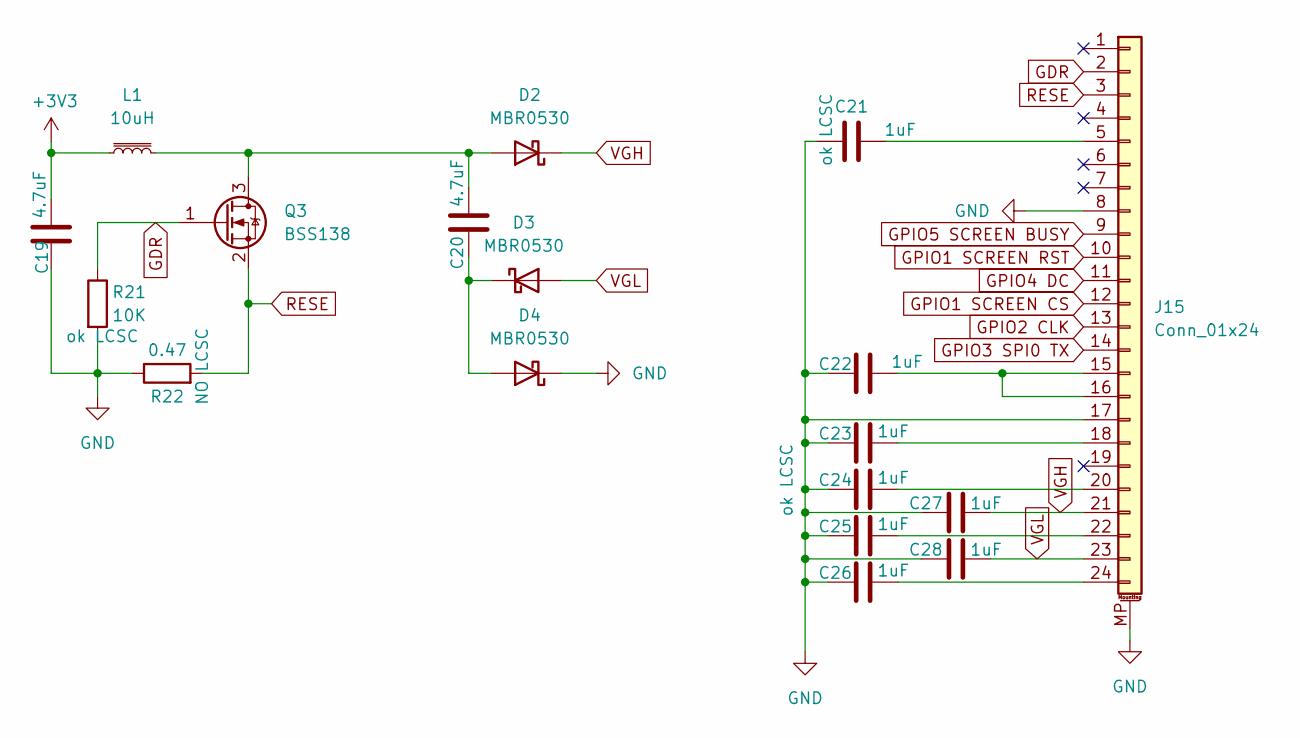
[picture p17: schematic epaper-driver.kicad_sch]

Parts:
C19, C20: 4.7uF; C_0603_1608Metric
C21, C22, C23, C24, C25, C26, C27, C28: 1uF; C_0603_1608Metric; LCSC C15849
D2, D3, D4: MBR0530; D_SOD-123
J15: Conn_01x24; Hirose_FH12-24S-0.5SH_1x24-1MP_P0.50mm_Horizontal
L1: 10uH; L_TDK_NLV32_3.2x2.5mm
Q3: BSS138; SOT-23-3
R21: 10K; R_0402_1005Metric; LCSC C25744
R22: 0.47; R_0603_1608Metric

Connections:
+3V3: C19.1, L1.1; also elsewhere on the board
GDR: J15.2, Q3.1 (G), R21.1
GND: C19.2, C21.2, C22.2, C23.2, C24.2, C25.2, C26.2, C27.2, C28.2, D4.1 (K), J15.8, J15.17, J15.MP (MountPin), R21.2, R22.1; also elsewhere on the board
GPIO1 SCREEN CS: J15.12; also elsewhere on the board
GPIO1 SCREEN RST: J15.10; also elsewhere on the board
GPIO2 CLK: J15.13; also elsewhere on the board
GPIO3 SPI0 TX: J15.14; also elsewhere on the board
GPIO4 DC: J15.11; also elsewhere on the board
GPIO5 SCREEN BUSY: J15.9; also elsewhere on the board
unnamed: C20.1, D2.2 (A), L1.2, Q3.3 (D)
unnamed: C20.2, D3.1 (K), D4.2 (A)
unnamed: C21.1, J15.5
unnamed: C22.1, J15.15, J15.16
unnamed: C23.1, J15.18
unnamed: C24.1, J15.20
unnamed: C25.1, J15.22
unnamed: C26.1, J15.24
RESE: J15.3, Q3.2 (S), R22.2
VGH: C27.1, D2.1 (K), J15.21
VGL: C28.1, D3.2 (A), J15.23

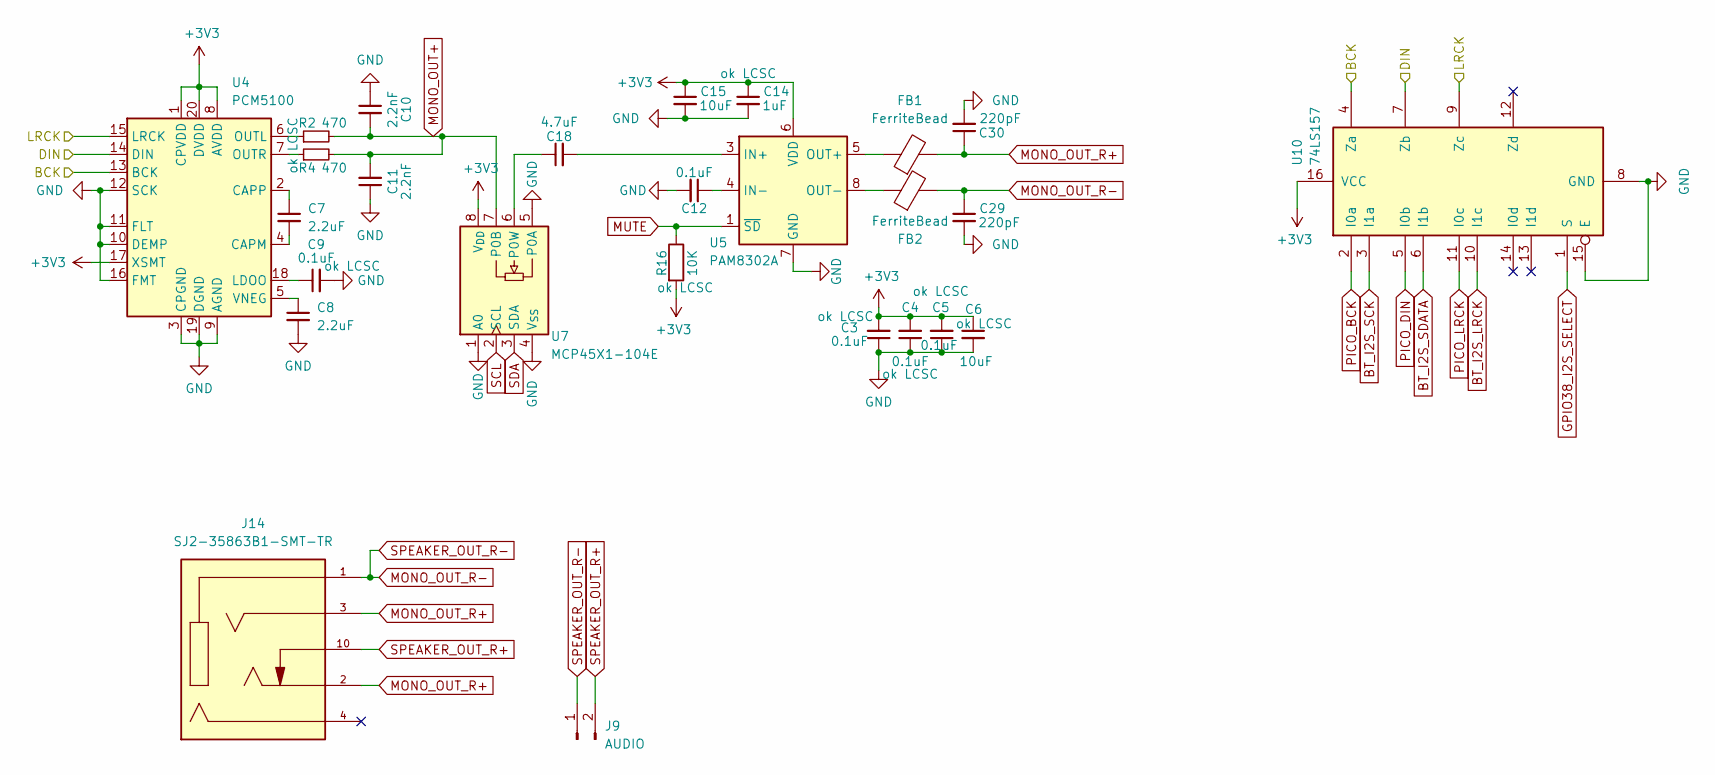
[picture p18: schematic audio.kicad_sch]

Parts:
C3, C4, C5, C9, C12: 0.1uF; C_0603_1608Metric; LCSC C14663
C6: 10uF; C_0805_2012Metric; LCSC C15850
C7: 2.2uF; C_0603_1608Metric
C8: 2.2uF; C_0402_1005Metric
C10, C11: 2.2nF; C_0603_1608Metric
C14: 1uF; C_0603_1608Metric; LCSC C15849
C15: 10uF; C_0603_1608Metric
C18: 4.7uF; C_0603_1608Metric
C29, C30: 220pF; C_0603_1608Metric
FB1, FB2: FerriteBead; L_0603_1608Metric
J9: AUDIO; PinHeader_1x02_P2.54mm_Vertical
J14: SJ2-35863B1-SMT-TR; CUI_SJ2-35863B1-SMT-TR; PARTREV 1.04
R2, R4: 470; R_0603_1608Metric; LCSC C23179
R16: 10K; R_0402_1005Metric; LCSC C25744
U4: PCM5100; TSSOP-20_4.4x6.5mm_P0.65mm
U5: PAM8302A; SOP-8_3.76x4.96mm_P1.27mm
U7: MCP45X1-104E; MSOP-8_3x3mm_P0.65mm
U10: 74LS157; SOP-16_4.55x10.3mm_P1.27mm

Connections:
+3V3: C3.2, C4.2, C5.2, C6.1, C14.1, C15.1, R16.2, U4.1 (CPVDD), U4.8 (AVDD), U4.17 (XSMT), U4.20 (DVDD), U5.6 (VDD), U7.8 (V_{DD}), U10.16 (VCC); also elsewhere on the board
/audio/BCK: U4.13 (BCK), U10.4 (Za)
/audio/DIN: U4.14 (DIN), U10.7 (Zb)
/audio/LRCK: U4.15 (LRCK), U10.9 (Zc)
BT_I2S_LRCK: U10.10 (I1c); also elsewhere on the board
BT_I2S_SCK: U10.3 (I1a); also elsewhere on the board
BT_I2S_SDATA: U10.6 (I1b); also elsewhere on the board
GND: C3.1, C4.1, C5.1, C6.2, C8.2, C9.2, C10.1, C11.1, C12.2, C14.2, C15.2, C29.2, C30.2, U4.3 (CPGND), U4.9 (AGND), U4.10 (DEMP), U4.11 (FLT), U4.12 (SCK), U4.16 (FMT), U4.19 (DGND), U5.7 (GND), U7.1 (A0), U7.4 (V_{SS}), U7.5 (P0A), U10.8 (GND), U10.15 (E); also elsewhere on the board
GPIO38_I2S_SELECT: U10.1 (S); also elsewhere on the board
MONO_OUT+: C10.2, C11.2, R2.2, R4.2, U7.7 (P0B)
MONO_OUT_R+: C30.1, FB1.2, J14.2, J14.3
MONO_OUT_R-: C29.1, FB2.2, J9.1, J14.1
MUTE: R16.1, U5.1 (~SD); also elsewhere on the board
unnamed: C7.2, U4.4 (CAPM)
unnamed: C7.1, U4.2 (CAPP)
unnamed: C9.1, U4.18 (LDOO)
unnamed: R2.1, U4.6 (OUTL)
unnamed: R4.1, U4.7 (OUTR)
unnamed: C8.1, U4.5 (VNEG)
unnamed: C18.2, U5.3 (IN+)
unnamed: C12.1, U5.4 (IN-)
unnamed: FB1.1, U5.5 (OUT+)
unnamed: FB2.1, U5.8 (OUT-)
unnamed: C18.1, U7.6 (P0W)
PICO_BCK: U10.2 (I0a); also elsewhere on the board
PICO_DIN: U10.5 (I0b); also elsewhere on the board
PICO_LRCK: U10.11 (I0c); also elsewhere on the board
SCL: U7.2 (SCL); also elsewhere on the board
SDA: U7.3 (SDA); also elsewhere on the board
SPEAKER_OUT_R+: J9.2, J14.10

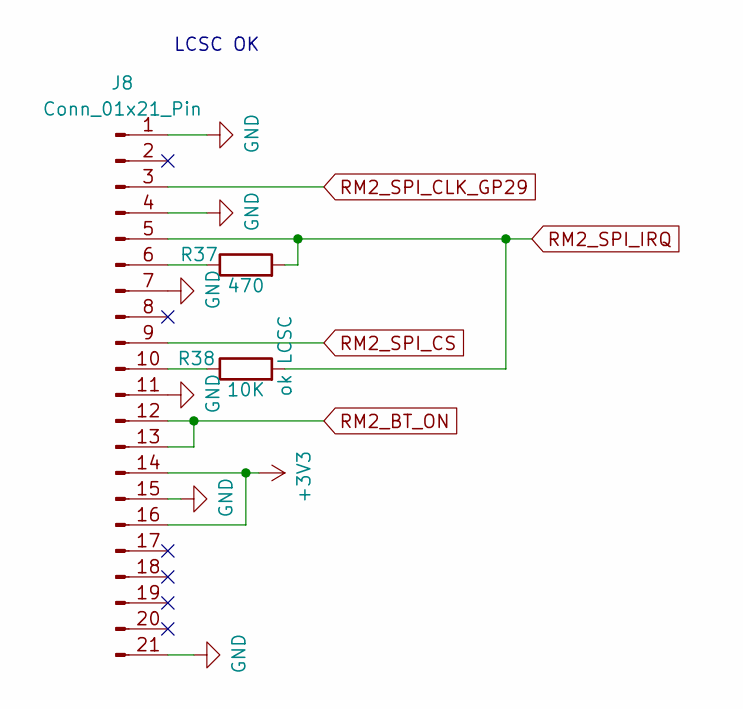
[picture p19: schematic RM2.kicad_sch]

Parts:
J8: Conn_01x21_Pin; RMC20452T
R37: 470; R_0603_1608Metric; LCSC C23179
R38: 10K; R_0402_1005Metric; LCSC C25744

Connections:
+3V3: J8.14, J8.16; also elsewhere on the board
GND: J8.1, J8.4, J8.7, J8.11, J8.15, J8.21; also elsewhere on the board
unnamed: J8.6, R37.1
unnamed: J8.10, R38.1
RM2_BT_ON: J8.12, J8.13; also elsewhere on the board
RM2_SPI_CLK_GP29: J8.3; also elsewhere on the board
RM2_SPI_CS: J8.9; also elsewhere on the board
RM2_SPI_IRQ: J8.5, R37.2, R38.2; also elsewhere on the board

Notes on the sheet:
LCSC OK

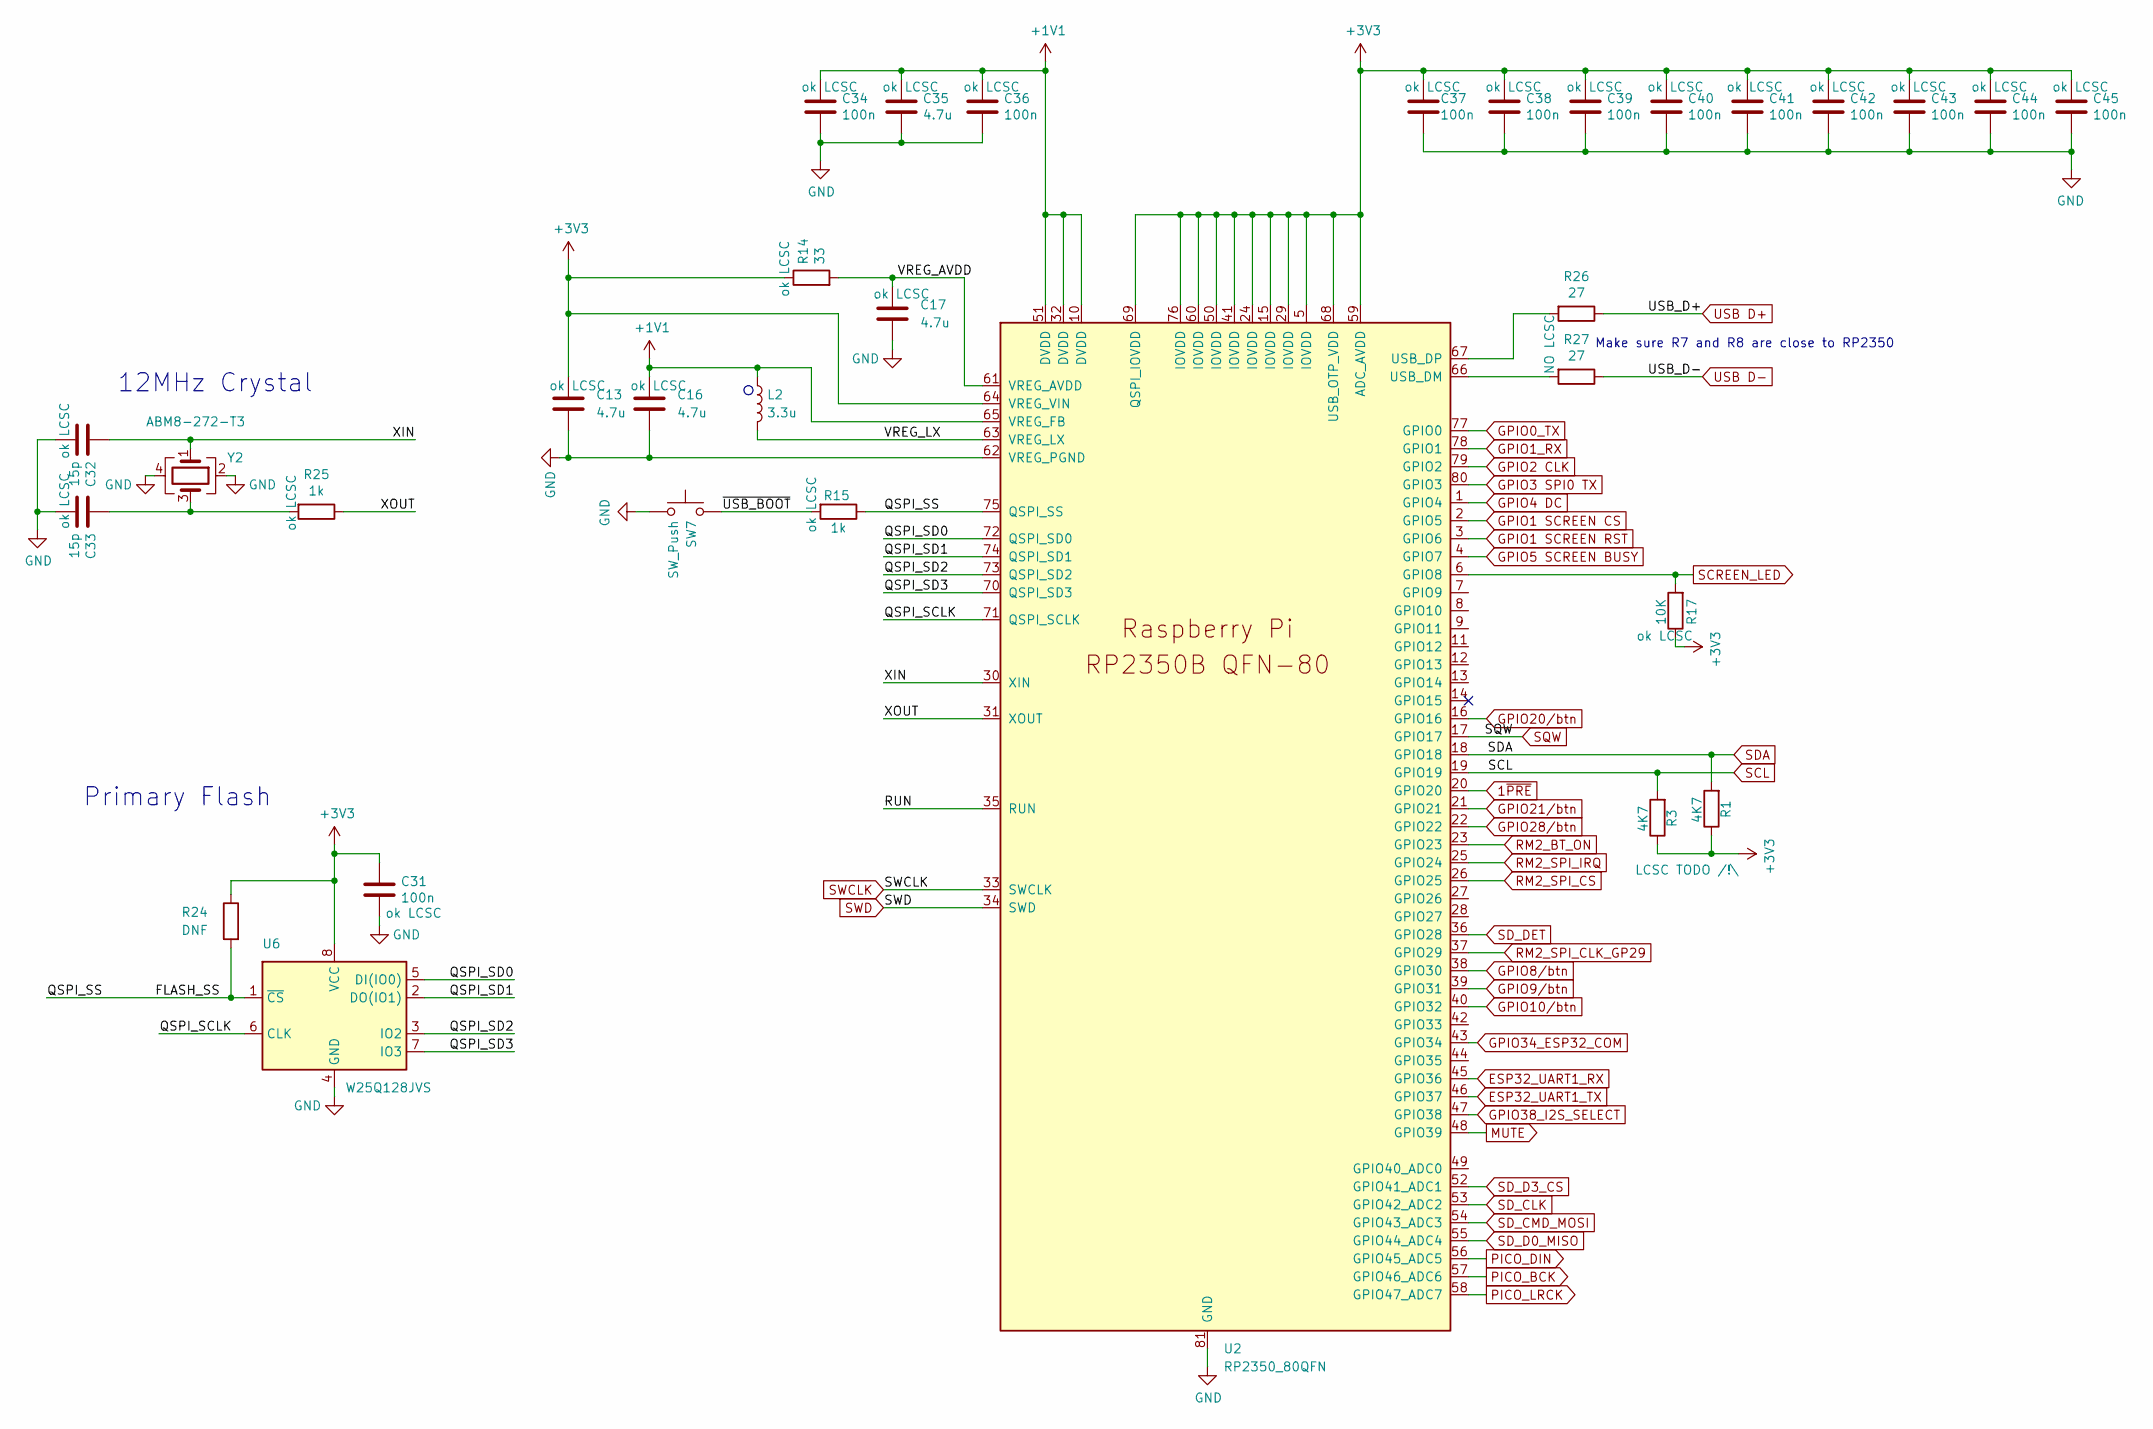
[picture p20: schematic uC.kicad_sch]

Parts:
C13, C16: 4.7u; C_0402_1005Metric_small_pads; LCSC C23733
C17, C35: 4.7u; C_0402_1005Metric; LCSC C23733
C31, C34, C36, C37, C38, C39, C40, C41, C42, C43, C44, C45: 100n; C_0402_1005Metric; LCSC C1525
C32, C33: 15p; C_0402_1005Metric; LCSC C1548
L2: 3.3u; L_pol_2016; LCSC C42411119
R1, R3: 4K7; R_0402_1005Metric
R14: 33; R_0402_1005Metric; LCSC C25105
R15, R25: 1k; R_0402_1005Metric; LCSC C11702
R17: 10K; R_0402_1005Metric; LCSC C25744
R24: DNF; R_0402_1005Metric
R26, R27: 27; R_0402_1005Metric
SW7: SW_Push; SW_Tactile_SPST_Angled_PTS645Vx31-2LFS
U2: RP2350_80QFN; RP2350-QFN-80-1EP_10x10_P0.4mm_EP3.4x3.4mm_ThermalVias; LCSC C39843328
U6: W25Q128JVS; SOIC-8_5.3x5.3mm_P1.27mm
Y2: ABM8-272-T3; Crystal_SMD_3225-4Pin_3.2x2.5mm

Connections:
1~PRE: U2.20 (GPIO20); also elsewhere on the board
+1V1: C16.1, C34.1, C35.1, C36.1, L2.1, U2.10 (DVDD), U2.32 (DVDD), U2.51 (DVDD), U2.65 (VREG_FB)
+3V3: C13.1, C31.1, C37.1, C38.1, C39.1, C40.1, C41.1, C42.1, C43.1, C44.1, C45.1, R1.1, R3.1, R14.1, R17.1, R24.1, U2.5 (IOVDD), U2.15 (IOVDD), U2.24 (IOVDD), U2.29 (IOVDD), U2.41 (IOVDD), U2.50 (IOVDD), U2.59 (ADC_AVDD), U2.60 (IOVDD), U2.64 (VREG_VIN), U2.68 (USB_OTP_VDD), U2.69 (QSPI_IOVDD), U2.76 (IOVDD), U6.8 (VCC); also elsewhere on the board
/uC/FLASH_SS: R15.1, R24.2, U2.75 (QSPI_SS), U6.1 (~CS)
/uC/QSPI_SCLK: U2.71 (QSPI_SCLK), U6.6 (CLK)
/uC/QSPI_SD0: U2.72 (QSPI_SD0), U6.5 (DI(IO0))
/uC/QSPI_SD1: U2.74 (QSPI_SD1), U6.2 (DO(IO1))
/uC/QSPI_SD2: U2.73 (QSPI_SD2), U6.3 (IO2)
/uC/QSPI_SD3: U2.70 (QSPI_SD3), U6.7 (IO3)
/uC/RUN: U2.35 (RUN)
/uC/VREG_AVDD: C17.1, R14.2, U2.61 (VREG_AVDD)
/uC/VREG_LX: L2.2, U2.63 (VREG_LX)
/uC/XIN: C32.1, U2.30 (XIN), Y2.1
/uC/XOUT: R25.1, U2.31 (XOUT)
/uC/~USB_BOOT: R15.2, SW7.2
ESP32_UART1_RX: U2.45 (GPIO36); also elsewhere on the board
ESP32_UART1_TX: U2.46 (GPIO37); also elsewhere on the board
GND: C13.2, C16.2, C17.2, C31.2, C32.2, C33.2, C34.2, C35.2, C36.2, C37.2, C38.2, C39.2, C40.2, C41.2, C42.2, C43.2, C44.2, C45.2, SW7.1, U2.62 (VREG_PGND), U2.81 (GND), U6.4 (GND), Y2.2, Y2.4; also elsewhere on the board
GPIO0_TX: U2.77 (GPIO0); also elsewhere on the board
GPIO1 SCREEN CS: U2.2 (GPIO5); also elsewhere on the board
GPIO1 SCREEN RST: U2.3 (GPIO6); also elsewhere on the board
GPIO1_RX: U2.78 (GPIO1); also elsewhere on the board
GPIO2 CLK: U2.79 (GPIO2); also elsewhere on the board
GPIO3 SPI0 TX: U2.80 (GPIO3); also elsewhere on the board
GPIO4 DC: U2.1 (GPIO4); also elsewhere on the board
GPIO5 SCREEN BUSY: U2.4 (GPIO7); also elsewhere on the board
GPIO8/btn: U2.38 (GPIO30); also elsewhere on the board
GPIO9/btn: U2.39 (GPIO31); also elsewhere on the board
GPIO10/btn: U2.40 (GPIO32); also elsewhere on the board
GPIO20/btn: U2.16 (GPIO16); also elsewhere on the board
GPIO21/btn: U2.21 (GPIO21); also elsewhere on the board
GPIO28/btn: U2.22 (GPIO22); also elsewhere on the board
GPIO34_ESP32_COM: U2.43 (GPIO34); also elsewhere on the board
GPIO38_I2S_SELECT: U2.47 (GPIO38); also elsewhere on the board
MUTE: U2.48 (GPIO39); also elsewhere on the board
unnamed: C33.1, R25.2, Y2.3
unnamed: R27.2, U2.66 (USB_DM)
unnamed: R26.2, U2.67 (USB_DP)
PICO_BCK: U2.57 (GPIO46_ADC6); also elsewhere on the board
PICO_DIN: U2.56 (GPIO45_ADC5); also elsewhere on the board
PICO_LRCK: U2.58 (GPIO47_ADC7); also elsewhere on the board
RM2_BT_ON: U2.23 (GPIO23); also elsewhere on the board
RM2_SPI_CLK_GP29: U2.37 (GPIO29); also elsewhere on the board
RM2_SPI_CS: U2.26 (GPIO25); also elsewhere on the board
RM2_SPI_IRQ: U2.25 (GPIO24); also elsewhere on the board
SCL: R3.2, U2.19 (GPIO19); also elsewhere on the board
SCREEN_LED: R17.2, U2.6 (GPIO8); also elsewhere on the board
SDA: R1.2, U2.18 (GPIO18); also elsewhere on the board
SD_CLK: U2.53 (GPIO42_ADC2); also elsewhere on the board
SD_CMD_MOSI: U2.54 (GPIO43_ADC3); also elsewhere on the board
SD_D0_MISO: U2.55 (GPIO44_ADC4); also elsewhere on the board
SD_D3_CS: U2.52 (GPIO41_ADC1); also elsewhere on the board
SD_DET: U2.36 (GPIO28); also elsewhere on the board
SQW: U2.17 (GPIO17); also elsewhere on the board
SWCLK: U2.33 (SWCLK); also elsewhere on the board
SWD: U2.34 (SWD); also elsewhere on the board
USB D+: R26.1; also elsewhere on the board
USB D-: R27.1; also elsewhere on the board

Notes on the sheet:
Make sure R7 and R8 are close to RP2350
12MHz Crystal
Primary Flash

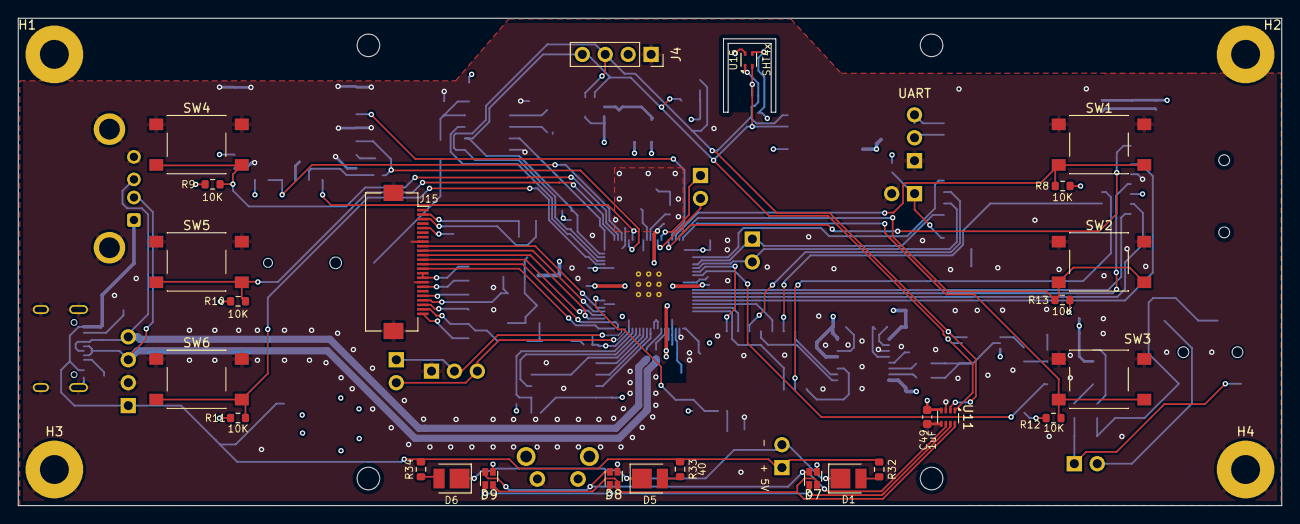
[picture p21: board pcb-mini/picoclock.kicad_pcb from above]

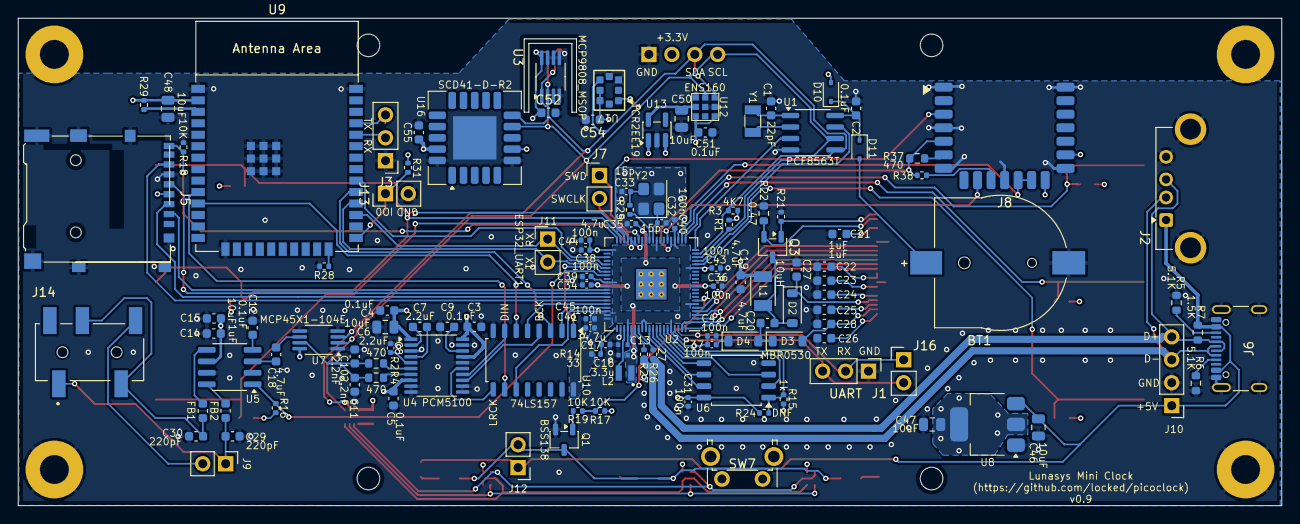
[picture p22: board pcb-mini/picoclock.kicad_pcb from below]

Board: 4 copper layers, 140.0 x 54.0 mm, 150 parts (120 on the bottom side), 113 nets.

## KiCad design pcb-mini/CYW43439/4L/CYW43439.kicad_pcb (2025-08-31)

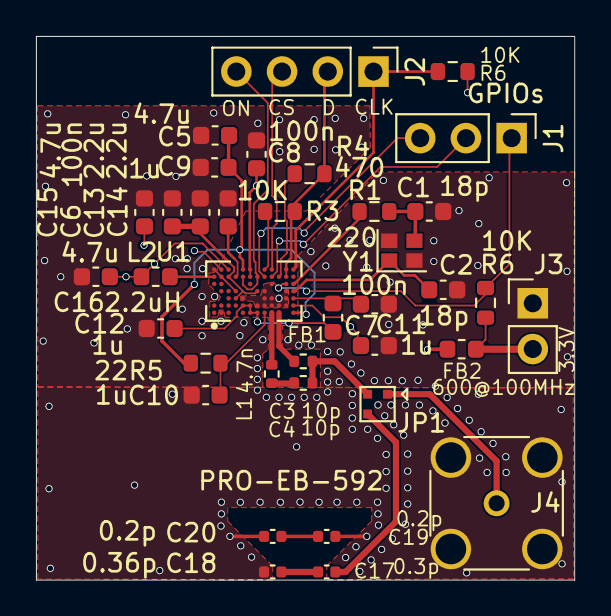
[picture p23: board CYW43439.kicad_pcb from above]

Board: 4 copper layers, 29.9 x 30.2 mm, 37 parts (0 on the bottom side), 31 nets.

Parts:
C1, C2: 18p; C_0603_1608Metric
C3, C4: 10p; R_0402_1005Metric
C5, C15, C16: 4.7u; C_0603_1608Metric
C6, C8, C11: 100n; C_0603_1608Metric
C7, C9, C10, C12: 1u; C_0603_1608Metric
C13, C14: 2.2u; C_0603_1608Metric
C17: 0.3p; C_0402_1005Metric
C18: 0.36p; C_0402_1005Metric
C19, C20: 0.2p; C_0402_1005Metric
FB1, FB2: 600@100MHz; L_0603_1608Metric
J1: GPIOs; PinHeader_1x03_P2.54mm_Vertical
J2: SPI; PinHeader_1x04_P2.54mm_Vertical
J3: Power; PinHeader_1x02_P2.54mm_Vertical
J4: RP-SMA Female; SMA_Amphenol_132134-14_Vertical
JP1: SolderJumper_3_Open; SolderJumper-3_P1.3mm_Open_Pad1.0x1.5mm
L1: 4.7n; R_0402_1005Metric
L2: 2.2uH; L_0603_1608Metric
R1: 220; R_0603_1608Metric
R3, R6, R6#2: 10K; R_0603_1608Metric
R4: 470; R_0603_1608Metric
R5: 22; R_0603_1608Metric
U1: CYW43439KUBGT; BGA63N40P7X12_287X487X55N
Y1: Crystal; Crystal_SMD_2016-4Pin_2.0x1.6mm

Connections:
+3.3V: FB2.2, J3.2, R6.2
ANTENNA: C17.1, JP1.3 (B)
BT_PAVDD: C10.1, R5.2, U1.H1 (BT_PAVDD)
GND: C1.2, C2.2, C5.2, C6.2, C7.2, C8.2, C9.2, C10.2, C11.2, C12.2, C13.2, C14.2, C15.2, C16.2, C18.2, C19.1, C20.2, J3.1, J4.2 (Ext), R6#2.2, U1.A7 (SR_PVSS), U1.B1 (BT_DEV_WAKE), U1.B6 (PMU_AVSS), U1.D4 (VSSC), U1.E3 (FM_RF_VSS), U1.G2 (BTFM_PLL_VSS), U1.H2 (BT_IF_VSS), U1.H3 (BT_VCO_VSS), U1.H4 (WLRF_AFE_GND), U1.J2 (WLRF_LNA_GND), U1.J3 (WLRF_GPIO), U1.J5 (VSSC), U1.K2 (WLRF_GENERAL_GND), U1.L2 (WLRF_PA_GND), U1.L3 (WLRF_VCO_GND), U1.L4 (WLRF_XTAL_GND), Y1.2, Y1.4
unnamed: C1.1, R1.2, Y1.3
unnamed: C4.1, L1.2
unnamed: C17.2, C18.1
unnamed: C19.2, C20.1
unnamed: J4.1 (In), JP1.1 (A)
unnamed: C3.2, C4.2, JP1.2 (C)
unnamed: C12.1, FB1.1, U1.E2 (FM_RF_VDD), U1.F1 (BT_VCO_VDD), U1.F2 (BTFM_PLL_VDD), U1.G1 (BT_IF_VDD)
unnamed: R4.1, U1.K6 (SDIO_DATA_0)
unnamed: R3.1, U1.H7 (SDIO_DATA_1)
unnamed: C3.1, U1.K1 (WLRF_2G_RF)
unnamed: R1.1, U1.M5 (WLRF_XTAL_XON)
unnamed: C2.1, U1.M4 (WLRF_XTAL_XOP), Y1.1
SR_VLX: L2.2, U1.A6 (SR_VLX)
VDDBAT: C8.1, C15.1, FB2.1, U1.B7 (SR_VDDBAT5V), U1.F6 (WCC_VDDIO), U1.F7 (LDO_VDDBAT5V)
VIN_LDO: C7.1, C16.1, L2.1, U1.C7 (LDO_VDD1P5), U1.M2 (WLRF_VDD_1P35)
VOUT_3P3: C5.1, C9.1, R5.1, U1.E7 (VOUT_3P3), U1.M1 (WLRF_PA_VDD)
VOUT_CORE: C6.1, C13.1, U1.C6 (VOUT_CLDO), U1.D3 (VDDC), U1.G4 (VDDC)
VOUT_LN: C14.1, U1.D6 (VOUT_LNLDO)
WLRF_2G_ELG: L1.1, U1.J1 (WLRF_2G_ELG)
WL_CLK: J2.1, R6#2.1, U1.M7 (SDIO_CLK)
WL_CS: J2.3, U1.J7 (SDIO_DATA_3)
WL_D: J2.2, R3.2, R4.2, U1.L6 (SDIO_CMD), U1.L7 (SDIO_DATA_2)
WL_GPIO0: J1.2, U1.J6 (GPIO_0)
WL_GPIO1: J1.3, U1.H6 (GPIO_1)
WL_GPIO2: J1.1, R6.1, U1.L5 (GPIO_2)
WL_ON: J2.4, U1.E6 (BT_REG_ON), U1.G6 (WL_REG_ON)
XTAL_VDD: C11.1, FB1.2, U1.M3 (WLRF_XTAL_VDD1P2)

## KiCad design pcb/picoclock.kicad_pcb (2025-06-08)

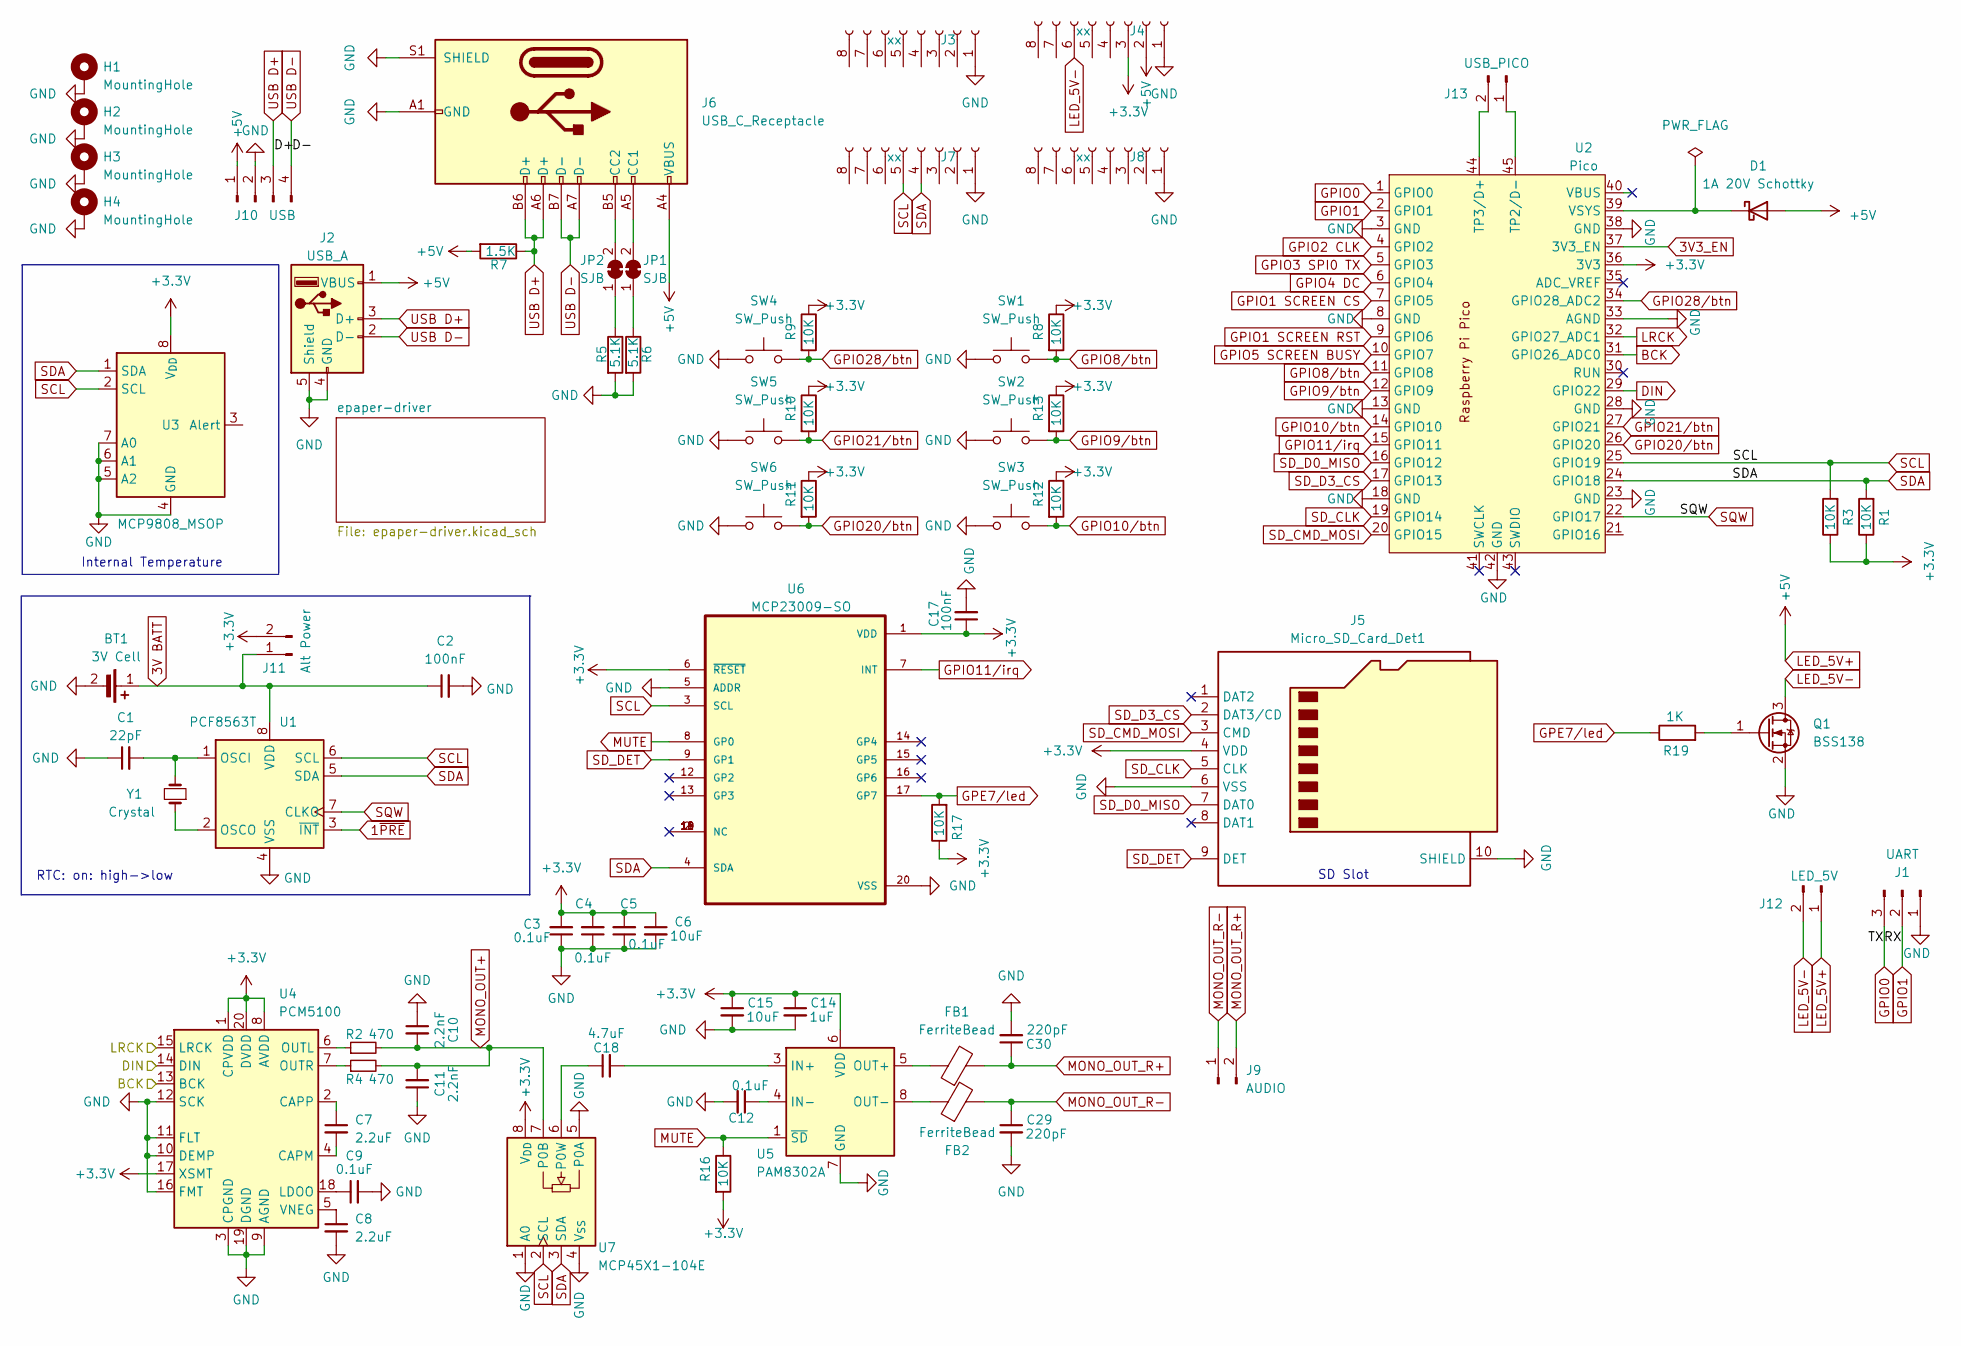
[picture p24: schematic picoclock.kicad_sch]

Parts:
BT1: 3V Cell; MPD_BC501SM-TR
C1: 22pF; C_0603_1608Metric; LCSC C1555
C2, C17: 100nF; C_0603_1608Metric; LCSC C1525
C3, C4, C5, C9, C12: 0.1uF; C_0603_1608Metric
C6: 10uF; C_0805_2012Metric
C7: 2.2uF; C_0603_1608Metric
C8: 2.2uF; C_0402_1005Metric
C10, C11: 2.2nF; C_0603_1608Metric
C14: 1uF; C_0603_1608Metric
C15: 10uF; C_0603_1608Metric
C18: 4.7uF; C_0603_1608Metric
C29, C30: 220pF; C_0603_1608Metric
D1: 1A 20V Schottky; D_SOD-123F; LCSC C169527
FB1, FB2: FerriteBead; L_0603_1608Metric
H1, H2, H3, H4: MountingHole; MountingHole_3.2mm_M3_Pad
J1: UART; PinHeader_1x03_P2.54mm_Vertical
J2: USB_A; USB_A_Connfly_DS1095
J3, J4, J7, J8: xx; PinSocket_1x08_P2.54mm_Vertical
J5: Micro_SD_Card_Det1; microSD_HC_Hirose_DM3AT-SF-PEJM5_combined_MSD-4-A
J6: USB_C_Receptacle; USB_C_Receptacle_GCT_USB4105-xx-A_16P_TopMnt_Horizontal
J9: AUDIO; PinHeader_1x02_P2.54mm_Vertical
J10: USB; PinHeader_1x04_P2.54mm_Vertical
J11: Alt Power; PinHeader_1x02_P2.54mm_Vertical
J12: LED_5V; PinHeader_1x02_P2.54mm_Vertical
J13: USB_PICO; PinHeader_1x02_P2.54mm_Vertical
JP1, JP2: SJB; SolderJumper-2_P1.3mm_Bridged_RoundedPad1.0x1.5mm
Q1: BSS138; SOT-23
R1, R3, R8, R9, R10, R11, R12, R13, R16, R17: 10K; R_0603_1608Metric; LCSC C25744
R2, R4: 470; R_0603_1608Metric
R5, R6: 5.1K; R_0603_1608Metric
R7: 1.5K; R_0603_1608Metric
R19: 1K; R_0603_1608Metric; LCSC C25744
SW1, SW2, SW3, SW4, SW5, SW6: SW_Push; SW_SPST_TL3301TG
U1: PCF8563T; SOIC-8_3.9x4.9mm_P1.27mm; LCSC C7440
U2: Pico; RPi_Pico_SMD_TH
U3: MCP9808_MSOP; MSOP-8_3x3mm_P0.65mm; LCSC C129490
U4: PCM5100; TSSOP-20_4.4x6.5mm_P0.65mm
U5: PAM8302A; SOP-8_3.76x4.96mm_P1.27mm
U6: MCP23009-SO; SOP65P780X200-20N; PARTREV C
U7: MCP45X1-104E; MSOP-8_3x3mm_P0.65mm
Y1: Crystal; Crystal_SMD_3215-2Pin_3.2x1.5mm; LCSC C32346

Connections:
1~PRE: U1.3 (~INT)
3V3_EN: U2.37 (3V3_EN)
3V BATT: BT1.1 (+), C2.1, J11.1, U1.8 (VDD)
+3.3V: C3.2, C4.2, C5.2, C6.1, C14.1, C15.1, C17.1, J4.3, J5.4 (VDD), J11.2, R1.1, R3.1, R8.1, R9.1, R10.1, R11.1, R12.1, R13.1, R16.2, R17.1, U2.36 (3V3), U3.8 (V_{DD}), U4.1 (CPVDD), U4.8 (AVDD), U4.17 (XSMT), U4.20 (DVDD), U5.6 (VDD), U6.1 (VDD), U6.6 (~RESET), U7.8 (V_{DD}); also elsewhere on the board
BCK: U2.31 (GPIO26_ADC0), U4.13 (BCK)
DIN: U2.29 (GPIO22), U4.14 (DIN)
GND: BT1.2 (-), C1.1, C2.2, C3.1, C4.1, C5.1, C6.2, C8.2, C9.2, C10.1, C11.1, C12.2, C14.2, C15.2, C17.2, C29.2, C30.2, H1.1, H2.1, H3.1, H4.1, J1.1, J2.4 (GND), J2.5 (Shield), J3.1, J4.1, J5.6 (VSS), J5.10 (SHIELD), J6.A1 (GND), J6.A12 (GND), J6.B1 (GND), J6.B12 (GND), J6.S1 (SHIELD), J7.1, J8.1, J10.2, Q1.2 (S), R5.2, R6.2, SW1.1, SW2.1, SW3.1, SW4.1, SW5.1, SW6.1, U1.4 (VSS), U2.3 (GND), U2.8 (GND), U2.13 (GND), U2.18 (GND), U2.23 (GND), U2.28 (GND), U2.33 (AGND), U2.38 (GND), U2.42 (GND), U3.4 (GND), U3.5 (A2), U3.6 (A1), U3.7 (A0), U4.3 (CPGND), U4.9 (AGND), U4.10 (DEMP), U4.11 (FLT), U4.12 (SCK), U4.16 (FMT), U4.19 (DGND), U5.7 (GND), U6.5 (ADDR), U6.20 (VSS), U7.1 (A0), U7.4 (V_{SS}), U7.5 (P0A); also elsewhere on the board
GPE7/led: R17.2, R19.1, U6.17 (GP7)
GPIO0: J1.3, U2.1 (GPIO0)
GPIO1: J1.2, U2.2 (GPIO1)
GPIO1 SCREEN CS: U2.7 (GPIO5); also elsewhere on the board
GPIO1 SCREEN RST: U2.9 (GPIO6); also elsewhere on the board
GPIO2 CLK: U2.4 (GPIO2); also elsewhere on the board
GPIO3 SPI0 TX: U2.5 (GPIO3); also elsewhere on the board
GPIO4 DC: U2.6 (GPIO4); also elsewhere on the board
GPIO5 SCREEN BUSY: U2.10 (GPIO7); also elsewhere on the board
GPIO8/btn: R8.2, SW1.2, U2.11 (GPIO8)
GPIO9/btn: R13.2, SW2.2, U2.12 (GPIO9)
GPIO10/btn: R12.2, SW3.2, U2.14 (GPIO10)
GPIO11/irq: U2.15 (GPIO11), U6.7 (INT)
GPIO20/btn: R11.2, SW6.2, U2.26 (GPIO20)
GPIO21/btn: R10.2, SW5.2, U2.27 (GPIO21)
GPIO28/btn: R9.2, SW4.2, U2.34 (GPIO28_ADC2)
LED_5V+: D1.2 (A), J2.1 (VBUS), J4.2, J6.A4 (VBUS), J6.A9 (VBUS), J6.B4 (VBUS), J6.B9 (VBUS), J10.1, J12.1, R7.2
LED_5V-: J4.6, J12.2, Q1.3 (D)
LRCK: U2.32 (GPIO27_ADC1), U4.15 (LRCK)
MONO_OUT+: C10.2, C11.2, R2.2, R4.2, U7.7 (P0B)
MONO_OUT_R+: C30.1, FB1.2, J9.2
MONO_OUT_R-: C29.1, FB2.2, J9.1
MUTE: R16.1, U5.1 (~SD), U6.8 (GP0)
unnamed: D1.1 (K), U2.39 (VSYS)
unnamed: J6.A5 (CC1), JP1.2 (B)
unnamed: J6.B5 (CC2), JP2.2 (B)
unnamed: J13.1, U2.45 (TP2/D-)
unnamed: J13.2, U2.44 (TP3/D+)
unnamed: JP1.1 (A), R6.1
unnamed: JP2.1 (A), R5.1
unnamed: Q1.1 (G), R19.2
unnamed: C1.2, U1.1 (OSCI), Y1.2
unnamed: U1.2 (OSCO), Y1.1
unnamed: C7.2, U4.4 (CAPM)
unnamed: C7.1, U4.2 (CAPP)
unnamed: C9.1, U4.18 (LDOO)
unnamed: R2.1, U4.6 (OUTL)
unnamed: R4.1, U4.7 (OUTR)
unnamed: C8.1, U4.5 (VNEG)
unnamed: C18.2, U5.3 (IN+)
unnamed: C12.1, U5.4 (IN-)
unnamed: FB1.1, U5.5 (OUT+)
unnamed: FB2.1, U5.8 (OUT-)
unnamed: C18.1, U7.6 (P0W)
SCL: J7.5, R3.2, U1.6 (SCL), U2.25 (GPIO19), U3.2 (SCL), U6.3 (SCL), U7.2 (SCL)
SDA: J7.4, R1.2, U1.5 (SDA), U2.24 (GPIO18), U3.1 (SDA), U6.4 (SDA), U7.3 (SDA)
SD_CLK: J5.5 (CLK), U2.19 (GPIO14)
SD_CMD_MOSI: J5.3 (CMD), U2.20 (GPIO15)
SD_D0_MISO: J5.7 (DAT0), U2.16 (GPIO12)
SD_D3_CS: J5.2 (DAT3/CD), U2.17 (GPIO13)
SD_DET: J5.9 (DET), U6.9 (GP1)
SQW: U1.7 (CLKO), U2.22 (GPIO17)
USB D+: J2.3 (D+), J6.A6 (D+), J6.B6 (D+), J10.3, R7.1
USB D-: J2.2 (D-), J6.A7 (D-), J6.B7 (D-), J10.4

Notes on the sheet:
SD Slot
Internal Temperature
RTC: on: high->low

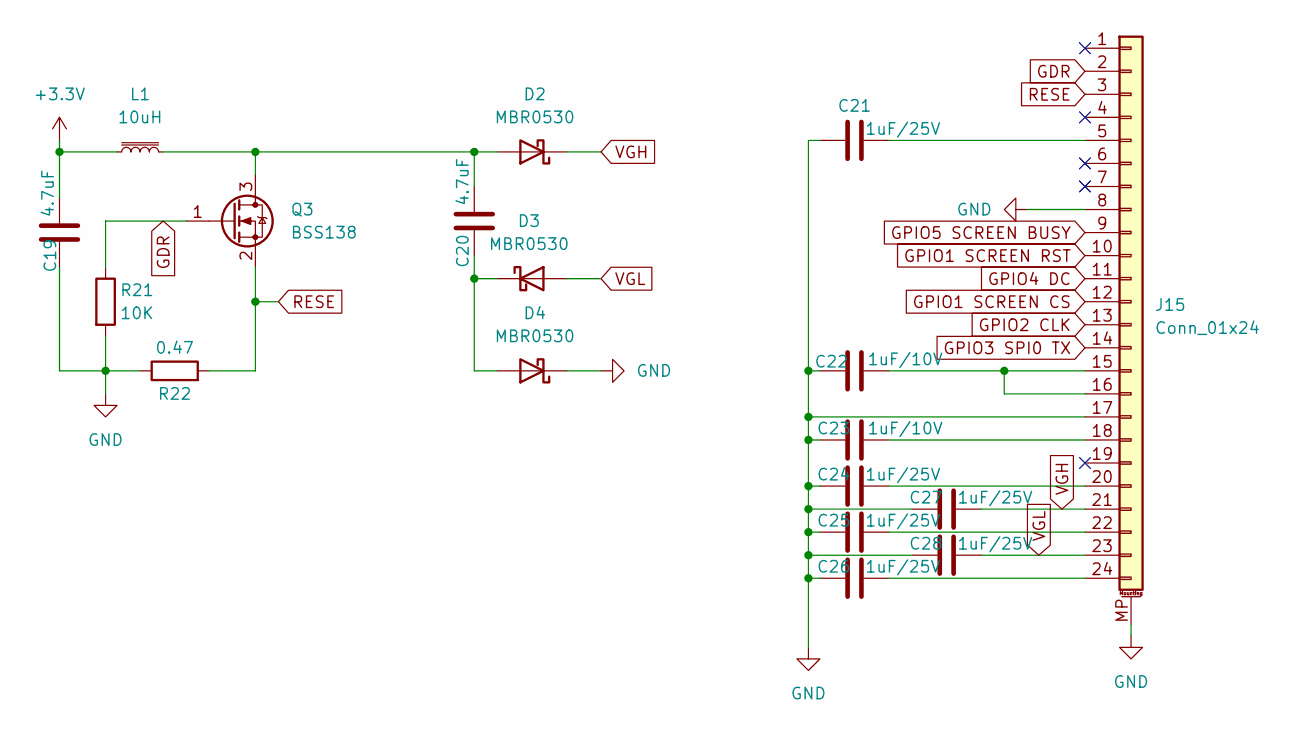
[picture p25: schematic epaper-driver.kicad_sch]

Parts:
C19, C20: 4.7uF; C_0603_1608Metric
C21, C24, C25, C26, C27, C28: 1uF/25V; C_0603_1608Metric
C22, C23: 1uF/10V; C_0603_1608Metric
D2, D3, D4: MBR0530; D_SOD-123
J15: Conn_01x24; Hirose_FH12-24S-0.5SH_1x24-1MP_P0.50mm_Horizontal
L1: 10uH; L_TDK_NLV32_3.2x2.5mm
Q3: BSS138; SOT-23-3
R21: 10K; R_0603_1608Metric
R22: 0.47; R_0603_1608Metric

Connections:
+3.3V: C19.1, L1.1; also elsewhere on the board
GDR: J15.2, Q3.1 (G), R21.1
GND: C19.2, C21.2, C22.2, C23.2, C24.2, C25.2, C26.2, C27.2, C28.2, D4.1 (K), J15.8, J15.17, J15.MP (MountPin), R21.2, R22.1; also elsewhere on the board
GPIO1 SCREEN CS: J15.12; also elsewhere on the board
GPIO1 SCREEN RST: J15.10; also elsewhere on the board
GPIO2 CLK: J15.13; also elsewhere on the board
GPIO3 SPI0 TX: J15.14; also elsewhere on the board
GPIO4 DC: J15.11; also elsewhere on the board
GPIO5 SCREEN BUSY: J15.9; also elsewhere on the board
unnamed: C20.1, D2.2 (A), L1.2, Q3.3 (D)
unnamed: C20.2, D3.1 (K), D4.2 (A)
unnamed: C21.1, J15.5
unnamed: C22.1, J15.15, J15.16
unnamed: C23.1, J15.18
unnamed: C24.1, J15.20
unnamed: C25.1, J15.22
unnamed: C26.1, J15.24
RESE: J15.3, Q3.2 (S), R22.2
VGH: C27.1, D2.1 (K), J15.21
VGL: C28.1, D3.2 (A), J15.23

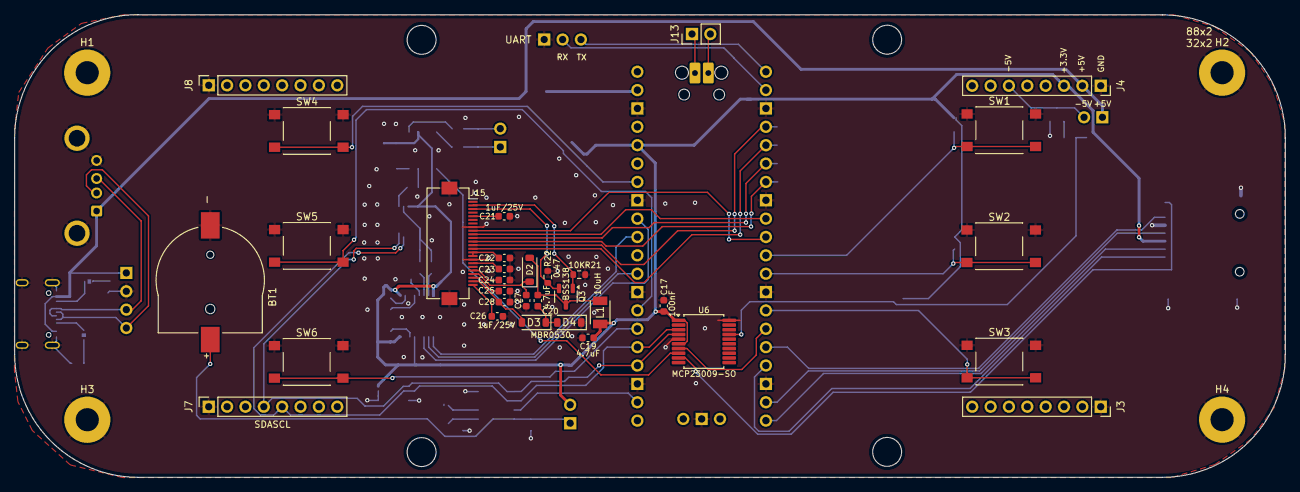
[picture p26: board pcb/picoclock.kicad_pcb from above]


Board: 2 copper layers, 175.8 x 64.0 mm, 90 parts (54 on the bottom side), 71 nets.

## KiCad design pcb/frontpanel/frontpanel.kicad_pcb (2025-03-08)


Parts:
D1, D2, D3, D4, D5, D6, D7, D8: LED; LED_0805_2012Metric
J1, J2, J3, J4: xx; PinSocket_1x08_P2.54mm_Vertical_SMD_Pin1Left
R1, R2, R3, R4: 68; R_0603_1608Metric
R5: 10K; R_0603_1608Metric
R6: 220; R_0603_1608Metric
U2: MCP9808_MSOP; MSOP-8_3x3mm_P0.65mm; LCSC C129490

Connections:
5V control: J1.6, R1.2, R2.2, R3.2, R4.2
+3.3V: J1.3, R6.2, U2.8 (V_{DD})
+5V: J1.2
GND: D2.1 (K), D3.1 (K), D5.1 (K), D8.1 (K), J1.1, J2.1, J3.1, J4.1, U2.4 (GND), U2.5 (A2), U2.6 (A1)
GPIO11: J1.8
unnamed: D1.2 (A), R1.1, R5.2
unnamed: D1.1 (K), D2.2 (A), R5.1
unnamed: D3.2 (A), D4.1 (K)
unnamed: D4.2 (A), R2.1
unnamed: D5.2 (A), D6.1 (K)
unnamed: D6.2 (A), R3.1
unnamed: D7.2 (A), R4.1
unnamed: D7.1 (K), D8.2 (A)
unnamed: R6.1, U2.7 (A0)
SCL: J1.5, U2.2 (SCL)
SDA: J1.4, U2.1 (SDA)


Board: 2 copper layers, 175.8 x 64.0 mm, 19 parts (19 on the bottom side), 14 nets.

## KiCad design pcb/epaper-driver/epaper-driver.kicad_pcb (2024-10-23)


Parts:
C1, C4, C5, C6, C7, C8: 1uF/25V; C_0603_1608Metric
C2, C3: 1uF/10V; C_0603_1608Metric
C9, C10: 4.7uF; C_0603_1608Metric
C11: 104; C_0603_1608Metric
D1, D2, D3: MBR0530; D_SOD-123
H1, H2: MountingHole; MountingHole_2.2mm_M2
J1: Main Conn; PinHeader_1x09_P2.54mm_Vertical
J2: Conn_01x24; Hirose_FH12-24S-0.5SH_1x24-1MP_P0.50mm_Horizontal
J3, J4: Conn_01x03_Pin; PinHeader_1x03_P1.00mm_Vertical
J5: Conn_01x03_Pin; PinHeader_1x03_P2.54mm_Vertical
J6: Conn_01x09_Pin
J8: SUPPORT; PinHeader_1x02_P2.54mm_Vertical
L1: 10uH; L_TDK_NLV32_3.2x2.5mm
Q1: BSS138; SOT-23-3
Q2: AO3401A; SOT-23-3
Q3: S8050; SOT-23-3
R1, R5: 10K; R_0603_1608Metric
R2: 0.47; R_0603_1608Metric
R3: 3; R_0603_1608Metric
R4: 27; R_0603_1608Metric
R6: 100K; R_0603_1608Metric
R7: 47K; R_0603_1608Metric

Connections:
+3.3V: C9.1, J3.1, J5.1, L1.1, Q2.2 (S)
BS: J2.8, J3.2
EPD_BUSY: J1.7, J2.9, J6.8
EPD_CS: J1.5, J2.12, J6.5
EPD_DC: J1.4, J2.11, J6.6
EPD_DIN: J1.3, J2.14, J6.3
EPD_PWR: J5.3, R4.2, R5.1
EPD_RST: J1.6, J2.10, J6.7
EPD_SCK: J1.2, J2.13, J6.4
GDR: J2.2, Q1.1 (G), R1.1
GND: C1.2, C2.2, C3.2, C4.2, C5.2, C6.2, C7.2, C8.2, C9.2, C11.2, D3.1 (K), J1.9, J2.17, J2.MP (MountPin), J3.3, J6.2, Q3.1 (E), R1.2, R2.1, R3.2, R6.2
unnamed: C10.1, D1.2 (A), L1.2, Q1.3 (D)
unnamed: C10.2, D2.1 (K), D3.2 (A)
unnamed: C1.1, J2.5
unnamed: C2.1, J2.15, J2.16
unnamed: C3.1, J2.18
unnamed: C4.1, J2.20
unnamed: C6.1, J2.22
unnamed: C8.1, J2.24
unnamed: J4.1, R2.2
unnamed: J4.3, R3.1
unnamed: Q2.1 (G), Q3.3 (C), R7.2
unnamed: Q3.2 (B), R5.2, R6.1
PWR_IN: J1.8, J5.2, J6.9
RESE: J2.3, J4.2, Q1.2 (S)
VCC_INT: C11.1, J6.1, J8.1, Q2.3 (D), R4.1, R7.1
VGH: C5.1, D1.1 (K), J2.21
VGL: C7.1, D2.2 (A), J2.23


Board: 2 copper layers, 31.7 x 29.2 mm, 34 parts (0 on the bottom side), 28 nets.

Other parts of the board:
H1#2: MountingHole; MountingHole_2.2mm_M2

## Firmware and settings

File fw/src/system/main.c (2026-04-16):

// C library
#include "main.h"
#include "debug.h"
#include "filesystem.h"
#include "sdcard.h"

#include <string.h>
#include <stdint.h>
#include <stdbool.h>
#include <stdlib.h>
#include <stdio.h>
#include <time.h>

#include "system.h"
#include "ui_task.h"
#include "net_task.h"
#include "alarms.h"
#include "fs_task.h"
#include "utils.h"
#include "fw.h"

// Raspberry Pico SDK
#include "pico/stdlib.h"
#include "hardware/uart.h"
#include "hardware/spi.h"
#include "hardware/dma.h"
#include "hardware/irq.h"
#include "hardware/pio.h"
#include "hardware/clocks.h"
#include "pico/util/datetime.h"
#include "pico/aon_timer.h"
#include "hardware/i2c.h"
#include "hardware/watchdog.h"
#include "pico/unique_id.h"
#include "pico.h"
#include "pico/multicore.h"
#include "pico/bootrom.h"

// Screen
#include "DEV_Config.h"
#include "GUI_Paint.h"
#include "ImageData.h"
#include "EPD_2in13_V4.h"
#include "EPD_2in13b_V4.h"

#include "lp5817/lp5817.h"
#include "mcp46XX/mcp45XX.h"
#include "pcf8563/pcf8563.h"
#include "ens160/ens160.h"
#include "mcp9808/mcp9808.h"
#include "senseair.h"
#include "btctrl.h"

#include "circularBuffer.h"

#include "sensirion/sensirion.h"

// Audio (PIO)
#include "audio_player.h"
#include "pico_i2s.h"
static __attribute__((aligned(8))) pio_i2s i2s;
static volatile uint32_t msTicks = 0;
audio_ctx_t audio_ctx;
static audio_i2s_config_t config = {
	.freq = 22050,
	.bps = 32,
	.data_pin = I2S_DATA_PIN,
	.clock_pin_base = I2S_CLOCK_PIN_BASE
};


// Globals
weather_struct weather = {"", "", "", ""};
config_struct global_config;
volatile features_t features = {false, false, false, false, false};
volatile int current_screen = 0;
char last_sync_str[9] = "";
volatile int reboot_requested = 0;
volatile bool refresh_screen = false;
volatile bool refresh_screen_clear = false;
volatile int ts_reset_alarm_screen = 0;
volatile bool sync_requested = false;
circularBuffer_t* ring_metrics;
volatile bool next_alarm_muted = false;

// CONSTANTS / DEFINES
const uint8_t BUTTONS[] = {BTN_1, BTN_2, BTN_3, BTN_4, BTN_5, BTN_6};
volatile uint8_t last_btn_values[6] = {1, 1, 1, 1, 1, 1};
volatile uint32_t last_btn_ts0[6] = {0, 0, 0, 0, 0, 0};
static struct repeating_timer timer;
volatile int request_btn_push = -1;
volatile int request_btn_long_push = -1;
volatile int request_audio_read = -1;
volatile bool request_audio_start = false;
volatile char request_audio_start_file[260] = "";

bool datetime_update_requested = true;
static struct repeating_timer timer_datetime;

volatile bool request_update = false;

//static __attribute__((aligned(4))) uint8_t workarea[4 * 1024];


// PROTOTYPES
extern void init_spi(void);
void dma_init();
void __isr __time_critical_func(audio_i2s_dma_irq_handler)();


void __not_in_flash_func(check_buttons)() {
	for (uint8_t btn=0; btn<6; btn++) {
		uint8_t btn_value = gpio_get(BUTTONS[btn]);
		if (btn_value == 1 && btn_value != last_btn_values[btn]) {
			if (last_btn_ts0[btn] > 0) {	// If 0, it means long push was already triggered
				request_btn_push = btn;
			}
		}
		if (btn_value == 0 && btn_value != last_btn_values[btn]) {
			last_btn_ts0[btn] = to_ms_since_boot(get_absolute_time());
		}
		if (btn_value == 0) {
			if (last_btn_ts0[btn] > 0) {
				uint32_t ts_diff = to_ms_since_boot(get_absolute_time()) - last_btn_ts0[btn];
				if (ts_diff > 2000 && ts_diff < 30000) {
					request_btn_long_push = btn;
					last_btn_ts0[btn] = 0;
				}
			}
		}
		last_btn_values[btn] = btn_value;
	}
}

bool timer_callback(struct repeating_timer *t) {
	check_buttons();
	return true; // Keep the timer running
}

bool timer_datetime_callback(struct repeating_timer *t) {
	datetime_update_requested = true;
	return true; // Keep the timer running
}


// ----------------------------------------------------------------------------
// AUDIO HAL
// ----------------------------------------------------------------------------
static void audio_callback(void) {
	main_audio_process();
}

void main_audio_play(const char *filename) {
	set_sys_clock_khz(CPU_CLOCK_MAX, true);

	printf("audio_play... [%s]\r\n", filename);
	audio_play(&audio_ctx, filename);
	config.freq = audio_ctx.audio_info.sample_rate;
	config.channels = audio_ctx.audio_info.channels;
	printf("pico_i2s_set_frequency...\r\n");
	pico_i2s_set_frequency(&i2s, &config);

	i2s.buffer_index = 0;

	// Fill 1st buffer..
	printf("audio_process 1st buffer...\r\n");
	audio_process(&audio_ctx);
	// ..then the 2nd one
	audio_process(&audio_ctx);

	gpio_put(AUDIO_MUTE_PIN, 1); // Unmute
	// Start DMA
	printf("i2s_start...\r\n");
	i2s_start(&i2s);
}

void main_audio_stop() {
	gpio_put(AUDIO_MUTE_PIN, 0); // Mute

	memset(i2s.out_ctrl_blocks[0], 0, STEREO_BUFFER_SIZE * sizeof(uint32_t));
	memset(i2s.out_ctrl_blocks[1], 0, STEREO_BUFFER_SIZE * sizeof(uint32_t));
	audio_stop(&audio_ctx);
	i2s_stop(&i2s);

	set_sys_clock_khz(CPU_CLOCK_IDLE, true);

	filesystem_unmount();
}

int main_audio_process() {
	return audio_process(&audio_ctx);
}

void main_audio_new_frame(const void *buff, int size) {
	if (size > STEREO_BUFFER_SIZE) {
		// Problème
		debug_printf("[picoclock] WARNING: audio_new_frame size:[%d] > STEREO_BUFFER_SIZE\n", size);
		return;
	}
	memcpy(i2s.out_ctrl_blocks[i2s.buffer_index], buff, size * sizeof(uint32_t));
	i2s.buffer_index = 1 - i2s.buffer_index;
}

void __isr __time_critical_func(audio_i2s_dma_irq_handler)() {
	//dma_hw->ints0 = 1u << i2s.dma_ch_out_data; // clear the IRQ
	dma_channel_acknowledge_irq0(i2s.dma_ch_out_data);

	// Warn the application layer that we have done on that channel
	request_audio_read = 1;
}


void init_i2c() {
	i2c_init(I2C_CHANNEL, I2C_BAUD_RATE);

	//printf("[picoclock] sensors: setting I2C pins: SDA=%d SCL=%d\n", SENSORS_SDA_PIN, SENSORS_SCL_PIN);
	gpio_set_function(I2C_SDA, GPIO_FUNC_I2C);
	gpio_set_function(I2C_SCL, GPIO_FUNC_I2C);

	//printf("[picoclock] sensors: pulling I2C pins up\n");
	gpio_pull_up(I2C_SDA);
	gpio_pull_up(I2C_SCL);
}

void init_gpio() {
	pio_set_gpio_base(pio0, 16);

	gpio_init(FRONT_PANEL_LED_PIN);
	gpio_set_dir(FRONT_PANEL_LED_PIN, GPIO_OUT);

	gpio_init(AUDIO_MUTE_PIN);
	gpio_set_dir(AUDIO_MUTE_PIN, GPIO_OUT);

	gpio_init(I2S_SELECT_PIN);
	gpio_set_dir(I2S_SELECT_PIN, GPIO_OUT);
	gpio_put(I2S_SELECT_PIN, 0);	// 0 select I2S from pico, 1 from ESP32

	// Buttons
	for (uint8_t btn=0; btn<6; btn++) {
		gpio_init(BUTTONS[btn]);
		gpio_set_dir(BUTTONS[btn], GPIO_IN);
		gpio_pull_up(BUTTONS[btn]);
	}
}

// I2C reserves some addresses for special purposes. We exclude these from the scan.
// These are any addresses of the form 000 0xxx or 111 1xxx
bool reserved_addr(uint8_t addr) {
    return (addr & 0x78) == 0 || (addr & 0x78) == 0x78;
}
void i2c_bus_scan() {
	printf("\nI2C Bus Scan\n");
	printf("   0  1  2  3  4  5  6  7  8  9  A  B  C  D  E  F\n");

	for (int addr = 0; addr < (1 << 7); ++addr) {
		if (addr % 16 == 0) {
			printf("%02x ", addr);
		}

		// Perform a 1-byte dummy read from the probe address. If a slave
		// acknowledges this address, the function returns the number of bytes
		// transferred. If the address byte is ignored, the function returns
		// -1.

		// Skip over any reserved addresses.
		int ret;
		uint8_t rxdata;
		if (reserved_addr(addr))
			ret = PICO_ERROR_GENERIC;
		else
			ret = i2c_read_blocking(I2C_CHANNEL, addr, &rxdata, 1, false);

		printf(ret < 0 ? "." : "@");
		printf(addr % 16 == 15 ? "\n" : "  ");
	}
	printf("Done.\n");
}


void system_initialize() {
	stdio_init_all();

	set_sys_clock_khz(CPU_CLOCK_IDLE, true);
	//set_sys_clock_khz(CPU_CLOCK_MAX, true);

	// Init UART
	stdio_uart_init_full(UART_ID, 9600, UART_TX_PIN, UART_RX_PIN);
	if (s88_get_co2() > 100) {
		features.has_s88 = true;
		// Disable stdio on UART since S88 is using it
		stdio_set_driver_enabled(&stdio_uart, false);
		//stdio_uart_deinit();
	} else {
		features.has_s88 = false;
		// No S88 detected, switch to 115200
		stdio_uart_deinit();
		stdio_uart_init_full(UART_ID, 115200, UART_TX_PIN, UART_RX_PIN);
		stdio_set_driver_enabled(&stdio_uart, true);
	}
	//gpio_set_function(UART_TX_PIN, GPIO_FUNC_UART);
	//gpio_set_function(UART_RX_PIN, GPIO_FUNC_UART);
	//uart_init(UART_ID, UART_BAUD_RATE);
	printf("[picoclock] START PICO_RP2350A=%d VERSION=%s\r\n", PICO_RP2350A, VERSION);

	// Display ROM boot info
    boot_info_t boot_info = {};
    int ret = rom_get_boot_info(&boot_info);
    printf("Boot partition is %d\n", boot_info.partition);

	// Init SDCARD
	gpio_init(SD_CARD_CS);
	gpio_put(SD_CARD_CS, 1);
	gpio_set_dir(SD_CARD_CS, GPIO_OUT);
	gpio_init(SD_CARD_PRESENCE);
	gpio_set_dir(SD_CARD_PRESENCE, GPIO_IN);
	// Init SPI
	spi_init(spi1, 1000 * 1000); // slow clock
	spi_set_format(spi1, 8, SPI_CPOL_0, SPI_CPHA_0, SPI_MSB_FIRST);
	gpio_set_function(SDCARD_SCK, GPIO_FUNC_SPI);
	gpio_set_function(SDCARD_MOSI, GPIO_FUNC_SPI);
	gpio_set_function(SDCARD_MISO, GPIO_FUNC_SPI);
	printf("[picoclock] Init SD card OK\r\n");

	// Init ring buffer for metrics
	ring_metrics = circularBuffer_create(ring_metrics, 65, sizeof(metrics_t));

	// Init I2C
	init_i2c();
	sleep_ms(1500);

	sensirion_init(I2C_CHANNEL);
	printf("[picoclock] Init SCD43\r\n");
	features.has_scd43 = sensirion_scd43_init();
	printf("[picoclock] Init STCC4\r\n");
	features.has_stcc4 = sensirion_stcc4_init();

	/*if (features.has_scd43) {
		sensirion_scd43_read();
	}
	if (features.has_stcc4) {
		sensirion_stcc4_read();
	}*/

	printf("[picoclock] features mcp9808:[%s] ens160:[%s] s88:[%s] stcc4:[%s] scd43:[%s]\r\n",
		features.has_mcp9808 ? "yes" : "no",
		features.has_ens160 ? "yes" : "no",
		features.has_s88 ? "yes" : "no",
		features.has_stcc4 ? "yes" : "no",
		features.has_scd43 ? "yes" : "no"
	);

	//i2c_bus_scan();

	pcf8563_set_i2c(I2C_CHANNEL);
	printf("[picoclock] pcf8563_set_i2c OK\r\n");

	init_gpio();

	// Init LED controller
	sleep_ms(2);
	lp5817_init(I2C_CHANNEL);
	lp5817_enable(true);
	lp5817_set_max_current_code();
	lp5817_set_dot_current(0, 0xff);	// Blue
	lp5817_set_dot_current(1, 0xff);	// Green
	lp5817_set_dot_current(2, 0xff);	// Red
	lp5817_set_output_enable_all();
	lp5817_update();

	// Init Sound
	mcp4551_init(I2C_CHANNEL);
	mcp4551_set_wiper(MCP4551_WIPER_MID); // 0 => high vol, 0xff => low vol

	i2s_program_setup(pio0, audio_i2s_dma_irq_handler, &i2s, &config);
	audio_init(&audio_ctx);
	printf("[picoclock] Init sound OK\r\n");

	// Init gaz sensor
	ens160_init(I2C_CHANNEL);
	uint8_t ens160_status = ens160_getFlags();
	features.has_ens160 = ens160_status == 0 || ens160_status == 1 || ens160_status == 2;

	// Init UART for ESP32 com
	btctrl_init(UART_ESP32_UART_ID, UART_ESP32_TX_PIN, UART_ESP32_RX_PIN);

	features.has_mcp9808 = mcp9808_detect() ? true : false;

	printf("[picoclock] System Clock: %lu\n", clock_get_hz(clk_sys));

	printf("[picoclock] features mcp9808:[%s] ens160:[%s] s88:[%s] stcc4:[%s] scd43:[%s]\r\n",
		features.has_mcp9808 ? "yes" : "no",
		features.has_ens160 ? "yes" : "no",
		features.has_s88 ? "yes" : "no",
		features.has_stcc4 ? "yes" : "no",
		features.has_scd43 ? "yes" : "no"
	);
}

void system_putc(char ch) {
	uart_putc_raw(UART_ID, ch);
}


// SDCARD HAL
void hal_sdcard_set_slow_clock() {
	spi_set_baudrate(spi1, 1000000UL);
}
void hal_sdcard_set_fast_clock() {
	spi_set_baudrate(spi1, 40000000UL);
}
void __no_inline_not_in_flash_func(hal_sdcard_cs_high)() {
	gpio_put(SD_CARD_CS, 1);
}
void __no_inline_not_in_flash_func(hal_sdcard_cs_low)() {
	gpio_put(SD_CARD_CS, 0);
}
void __no_inline_not_in_flash_func(hal_sdcard_spi_exchange)(const uint8_t *buffer, uint8_t *out, uint32_t size) {
	spi_write_read_blocking(spi1, buffer, out, size);
}
void __no_inline_not_in_flash_func(hal_sdcard_spi_write)(const uint8_t *buffer, uint32_t size) {
	spi_write_blocking(spi1, buffer, size);
}
void __no_inline_not_in_flash_func(hal_sdcard_spi_read)(uint8_t *out, uint32_t size) {
	spi_read_blocking(spi1, 0xFF, out, size);
}
uint8_t __no_inline_not_in_flash_func(hal_sdcard_get_presence)() {
	printf("[sdcard] gpio_get(SD_CARD_PRESENCE):[%d] (0==present)\r\n", gpio_get(SD_CARD_PRESENCE));
	return gpio_get(SD_CARD_PRESENCE) == 0;
}

uint32_t __no_inline_not_in_flash_func(get_fattime) (void) {
	return 0;
}


void core1_entry() {
	flash_safe_execute_core_init();
	multicore_lockout_victim_init();

	int last_min = 0;
	int last_sync = -1;
	time_struct dt;
	metrics_t metrics;

	printf("[core1] check RTC\r\n");
	dt = pcf8563_getDateTime();
	if (dt.volt_low) {
		printf("[core1] check RTC => low volt, trigger sync\r\n");
		remote_sync();
	}

	// Negative delay means "run every X ms from the start of the last run"
	add_repeating_timer_ms(-10, timer_callback, NULL, &timer);

	add_repeating_timer_ms(-1000, timer_datetime_callback, NULL, &timer_datetime);

	refresh_screen = true;
	printf("[core1] start loop\r\n");
	while (1) {
		if (datetime_update_requested) {
			datetime_update_requested = false;
			dt = pcf8563_getDateTime();
			//printf("[core1] update time:[%d] [%d:%d]\r\n", dt.volt_low, dt.hour, dt.min);
		}

		// Check alarm
		if (dt.min != last_min) {
			if (check_alarm(dt) == 1) {
				ts_reset_alarm_screen = dt.hour * 3600 + dt.min * 60 + dt.sec + 120;  // To reset screen after a while

				// Set screen to alarm
				current_screen = SCREEN_ALARM;
				refresh_screen = true;
				refresh_screen_clear = true;
			}

			// Collect metrics
			printf("[picoclock] features mcp9808:[%s] ens160:[%s] s88:[%s] stcc4:[%s] scd43:[%s]\r\n",
				features.has_mcp9808 ? "yes" : "no",
				features.has_ens160 ? "yes" : "no",
				features.has_s88 ? "yes" : "no",
				features.has_stcc4 ? "yes" : "no",
				features.has_scd43 ? "yes" : "no"
			);
			metrics.year = dt.year;
			metrics.month = dt.month;
			metrics.day = dt.day;
			metrics.hour = dt.hour;
			metrics.min = dt.min;
			metrics.temp = features.has_mcp9808 ? mcp9808_get_temperature() : -9999;
			if (features.has_ens160) {
				ens160_setTempCompensationCelsius(metrics.temp);
				metrics.tvoc = ens160_getTVOC();
				metrics.eco2 = ens160_getECO2();
				metrics.ens160_status = ens160_getFlags();
			} else {
				metrics.tvoc = -1;
				metrics.eco2 = -1;
				metrics.ens160_status = -1;
			}
			metrics.s88_co2 = features.has_s88 ? s88_get_co2() : 0;
			metrics.scd43_co2 = features.has_scd43 ? sensirion_scd43_read() : -1;
			if (to_ms_since_boot(get_absolute_time()) > 180000) {	// Do not store values just after boot
				metrics.stcc4_co2 = features.has_stcc4 ? sensirion_stcc4_read() : -1;
			}
			metrics.mem_free = getFreeHeap();
			metrics.sent = false;
			circularBuffer_insert(ring_metrics, &metrics);
			/*for (uint8_t i = 0; i < ring_metrics->num; i++) {
				metrics_t *m = (metrics_t*)circularBuffer_getElement(ring_metrics, i);
				printf("co2:%d eco2:%d ens160_status:%d ", m->co2, m->eco2, m->ens160_status);
			}
			printf("\n");*/

			refresh_screen = true;
			refresh_screen_clear = false;

			last_min = dt.min;
		}

		if (!dt.volt_low) {
			// Trigger sync periodically
			int ts = dt.hour * 3600 + dt.min * 60 + dt.sec;
			if (last_sync == -1) {
				// First run, initialize as if sync nearly 1 hour ago
				last_sync = ts - TRIGGER_SYNC_EVERY_SEC + 30;
			}
			bool old_sync = ((ts - last_sync) > TRIGGER_SYNC_EVERY_SEC) || ((ts - last_sync) < 0);
			if ((sync_requested || old_sync) && !audio_ctx.playing) {
				sync_requested = false;
				last_sync = ts;
				printf("ts:[%d] last_sync:[%d] ts - last_sync:[%d] => Trigger server sync\r\n", ts, last_sync, ts - last_sync);
				int ret = remote_sync();
				if (request_update) {
					cancel_repeating_timer(&timer);
					cancel_repeating_timer(&timer_datetime);
					while (1) {
						sleep_ms(60000);
					}
				}

				if (ret == 1) {
					// On error, retry earlier
					last_sync = ts - TRIGGER_SYNC_EVERY_SEC + 5 * 60;
				} else {
					refresh_screen = true;
				}
				sprintf(last_sync_str, "%02d:%02d:%02d", dt.hour, dt.min, dt.sec);
				printf("sync trigger done\r\n");
			}

			// Reset alarm screen after a while
			if (ts_reset_alarm_screen > 0 && ts > ts_reset_alarm_screen) {
				printf("ts:[%d] ts_reset_alarm_screen:[%d] => Reset alarm screen\r\n", ts, ts_reset_alarm_screen);
				ts_reset_alarm_screen = 0;
				// Set screen back to normal mode
				current_screen = SCREEN_MAIN;
				// And force refresh
				refresh_screen = true;
				refresh_screen_clear = true;
			}
		}
		if (request_btn_push >= 0) {
			ui_btn_click(request_btn_push, dt);
			request_btn_push = -1;
		}
		if (request_btn_long_push >= 0) {
			ui_btn_long_click(request_btn_long_push, dt);
			request_btn_long_push = -1;
		}
		if (refresh_screen) {
			ui_refresh_screen(refresh_screen_clear, dt);
			refresh_screen = false;
		}
		sleep_ms(50);
		screen_anim();
		watchdog_update();
	}
}

// ===========================================================================================================
// MAIN ENTRY POINT
// ===========================================================================================================
int main() {
	system_initialize();

	printf("[picoclock] main(0) features mcp9808:[%s] ens160:[%s] s88:[%s] stcc4:[%s] scd43:[%s]\r\n",
		features.has_mcp9808 ? "yes" : "no",
		features.has_ens160 ? "yes" : "no",
		features.has_s88 ? "yes" : "no",
		features.has_stcc4 ? "yes" : "no",
		features.has_scd43 ? "yes" : "no"
	);

	// Test the printf output
	printf("[picoclock] Starting: V%d.%d\r\n", 1, 0);

	// Init config with default values
	strncpy(global_config.wifi_ssid, WIFI_SSID, 50);
	strncpy(global_config.wifi_key, WIFI_PASSWORD, 50);
	strncpy(global_config.remote_host, SERVER_IP, 50);
	strncpy(global_config.screen, "4", 2); // "4" (B/W) or "B" (Color)

	// Filesystem / SDCard initialization
	printf("[picoclock] Check SD card\r\n");
	watchdog_update();
	filesystem_mount();
	// List files on sdcard (test)
	filesystem_read_config_file();
	//request_update = filesystem_fw_file_exists();
	/*boot_info_t boot_info = {};
	int ret = rom_get_boot_info(&boot_info);
	if (rom_get_last_boot_type() == BOOT_TYPE_FLASH_UPDATE) {
		printf("[picoclock] Someone updated into me\n");
		if (boot_info.reboot_params[0]) printf("Flash update base was %x\n", boot_info.reboot_params[0]);
		if (boot_info.tbyb_and_update_info) printf("Update info %x\n", boot_info.tbyb_and_update_info);
		ret = rom_explicit_buy(workarea, sizeof(workarea));
		if (ret) printf("[picoclock] Buy returned %d\n", ret);
		ret = rom_get_boot_info(&boot_info);
		if (boot_info.tbyb_and_update_info) printf("[picoclock] Update info now %x\n", boot_info.tbyb_and_update_info);
	}*/
	filesystem_unmount();

	watchdog_enable(8200, false);

	// Init screen
	//------------------- Init LCD
	printf("[picoclock] Init e-Paper module...\r\n");
	if (DEV_Module_Init() == 0) {
		if (strcmp(global_config.screen, "B") == 0) {
			printf("[picoclock] e-Paper module: B\r\n");
			//EPD_2IN13B_V4_Init();
			printf("[picoclock] e-Paper module: B init OK\r\n");
			//EPD_2IN13B_V4_Clear();
			printf("[picoclock] e-Paper module: B clear OK\r\n");
			DEV_Delay_ms(500);
		} else {
			printf("[picoclock] e-Paper module: V4\r\n");
			watchdog_update();
			EPD_2in13_V4_Init();
			printf("[picoclock] e-Paper module: V4 init OK\r\n");
			watchdog_update();
			EPD_2in13_V4_Clear();
			printf("[picoclock] e-Paper module: V4 clear OK\r\n");
		}
	}

	printf("[picoclock] Init UI\r\n");
	init_ui();

	printf("[picoclock] Start\r\n");

	multicore_launch_core1(core1_entry);

	while (true) {
		//printf("[picoclock] In loop\r\n");
		uint64_t sleep_dur = 10000;
		if (audio_ctx.playing) {
			sleep_dur = 50;		// I2S audio data cannot wait
		}
		sleep_us(sleep_dur);
		if (request_audio_start) {
			printf("[picoclock] found file to play:[%s]\r\n", request_audio_start_file);
			fs_task_sound_start(request_audio_start_file);
			request_audio_start = false;
		}
		if (request_audio_read > 0) {
			fs_audio_next_samples();
			request_audio_read = -1;
		}
		if (request_update) {
			printf("[picoclock] fw update requested, wait a bit then start\r\n");
			sleep_ms(3000);
			//multicore_lockout_start_blocking();
			multicore_reset_core1();
			printf("[picoclock] shutdown screen\r\n");
			screen_shutdown();
			printf("[picoclock] mount fs\r\n");
			filesystem_mount();
			printf("[picoclock] fw_update_init\r\n");
			fw_update_init();
			printf("[picoclock] fw_update start\r\n");
			filesystem_read_fw_file(process_ota_segment);
			filesystem_unmount();
			multicore_lockout_end_blocking();
			request_update = false;
		}
	}

	return 0;
}

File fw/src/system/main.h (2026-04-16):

#ifndef MAIN_H
#define MAIN_H

#ifdef __cplusplus
extern "C"
{
#endif

#include <stdint.h>
#include "pcf8563/pcf8563.h"

#define VERSION "0.60"

#define CPU_CLOCK_IDLE 100000
#define CPU_CLOCK_MAX 200000

// normal screens
#define SCREEN_MAIN 0
#define SCREEN_WEATHER 1
#define SCREEN_LIST_ALARMS 2
#define SCREEN_DEBUG 3
// unreachable screens
#define SCREEN_ALARM 10
#define SCREEN_MUSIC 11
#define SCREEN_MUSIC_BT 12

#define MAX_SCREEN_ID 3

#define UART_ID uart0
//#define UART_BAUD_RATE 115200
//#define UART_BAUD_RATE 9600
#define UART_TX_PIN 0
#define UART_RX_PIN 1

// UART for ESP32 communication
#define UART_ESP32_UART_ID uart1
#define UART_ESP32_TX_PIN 36
#define UART_ESP32_RX_PIN 37

// Can be:
// 1, 2, mini
#define PCB_VERSION_1 1
#define PCB_VERSION_2 2
#define PCB_VERSION_MINI mini
#define PCB_VERSION PCB_VERSION_MINI

#if PCB_VERSION == PCB_VERSION_1
#define BTN_1 8
#define BTN_2 9
#define BTN_3 10
#define BTN_4 19
#define BTN_5 20
#define BTN_6 21
#define FRONT_PANEL_LED_PIN 11
#endif
#if PCB_VERSION == PCB_VERSION_2
// PCBv2 OK
#define BTN_1 8
#define BTN_2 9
#define BTN_3 10
#define BTN_4 20
#define BTN_5 21
#define BTN_6 28
#define FRONT_PANEL_LED_PIN 7	// on gpio extender
#endif
#if PCB_VERSION == PCB_VERSION_MINI
#define BTN_1 30
#define BTN_2 31
#define BTN_3 32
#define BTN_4 20
#define BTN_5 21
#define BTN_6 22
#define FRONT_PANEL_LED_PIN 8
#endif

#if PCB_VERSION == PCB_VERSION_1
#define I2C_SDA 12
#define I2C_SCL 13
#define I2C_CHANNEL i2c0
#endif
#if PCB_VERSION == PCB_VERSION_2
#define I2C_SDA 18
#define I2C_SCL 19
#define I2C_CHANNEL i2c1
#endif
#if PCB_VERSION == PCB_VERSION_MINI
#define I2C_SDA 18
#define I2C_SCL 19
#define I2C_CHANNEL i2c1
#endif
#define I2C_BAUD_RATE 100000
//#define I2C_BAUD_RATE 400000


#if PCB_VERSION == PCB_VERSION_MINI
#define I2S_DATA_PIN 45
#define I2S_CLOCK_PIN_BASE 46
//#define I2S_DATA_PIN 20        // OK
//#define I2S_CLOCK_PIN_BASE 21  // OK
#define AUDIO_MUTE_PIN 39
#define I2S_SELECT_PIN 38
#else
#define I2S_DATA_PIN 22
#define I2S_CLOCK_PIN_BASE 26
#define AUDIO_MUTE_PIN 0 // on gpio extender
#endif


#if PCB_VERSION == PCB_VERSION_MINI
#define SDCARD_SCK 42
#define SDCARD_MOSI 43
#define SDCARD_MISO 44
#define SD_CARD_CS 41
#define SD_CARD_PRESENCE 28
#else
#define SDCARD_SCK 14
#define SDCARD_MOSI 15
#define SDCARD_MISO 12
#define SD_CARD_CS 13
#define SD_CARD_PRESENCE 2	// on gpio extender
#endif

#define TRIGGER_SYNC_EVERY_SEC 1800

typedef void (*wifi_callback_t)(char *buffer, uint16_t buffer_length);

typedef int (*ota_segment_consumer_t)(char* buf);

typedef struct {
	char code_desc[100];
	char temperature_2m[20];
	char wind_speed_10m[20];
	char precipitation[20];
	int day_0_precip_sum;
	int day_0_temp_min;
	int day_0_temp_max;
	char day_0_sunrise[6];
	char day_0_sunset[6];
	int day_1_precip_sum;
	int day_1_temp_min;
	int day_1_temp_max;
	char day_1_sunrise[6];
	char day_1_sunset[6];
	int day_2_precip_sum;
	int day_2_temp_min;
	int day_2_temp_max;
	char day_2_sunrise[6];
	char day_2_sunset[6];
} weather_struct;

typedef struct {
	char wifi_ssid[50];
	char wifi_key[50];
	char remote_host[50];
	char screen[2];
} config_struct;

typedef struct {
	uint8_t year;
	uint8_t month;
	uint8_t day;
	uint8_t hour;
	uint8_t min;
	uint16_t tvoc;
	uint16_t eco2;
	uint16_t s88_co2;
	int16_t scd43_co2;
	int16_t stcc4_co2;
	uint8_t ens160_status;
	uint32_t mem_free;
	float temp;
	bool sent;
	bool tosend;
} metrics_t;

typedef struct {
	int has_mcp9808;
	int has_ens160;
	int has_s88;
	int has_stcc4;
	int has_scd43;
} features_t;

// System API
void system_initialize();
void system_putc(char ch);

// Audio API
void main_audio_play(const char *filename);
void main_audio_stop();
int main_audio_process();
void main_audio_new_frame(const void *buffer, int size);

// SDCARD HAL
void hal_sdcard_set_slow_clock(void);
void hal_sdcard_set_fast_clock(void);

// Deselect the SD-Card by driving the Chip Select to high level (eg: 3.3V)
void hal_sdcard_cs_high();
// Deselect the SD-Card by driving the Chip Select to low level (eg: 0V)
void hal_sdcard_cs_low();

// We have a separated API here to allow specific optimizations such as the use of DMA
void hal_sdcard_spi_exchange(const uint8_t *buffer, uint8_t *out, uint32_t size);
void hal_sdcard_spi_write(const uint8_t *buffer, uint32_t size);
void hal_sdcard_spi_read(uint8_t *out, uint32_t size);

// Return 1 if the SD card is physically inserted, otherwise 0
uint8_t hal_sdcard_get_presence();

uint32_t get_fattime (void);

#ifdef __cplusplus
}
#endif

#endif // MAIN_H

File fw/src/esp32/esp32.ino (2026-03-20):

#include "ESP_I2S.h"
#include "AudioTools.h"
#include "BluetoothA2DPSink.h"

const uint8_t RX1PIN = 16;
const uint8_t TX1PIN = 17;

const uint8_t I2S_SCK = 5;       // Audio data bit clock
const uint8_t I2S_WS = 25;       // Audio data left and right clock
const uint8_t I2S_SDOUT = 26;    // ESP32 audio data output (to speakers)
I2SClass i2s;

BluetoothA2DPSink a2dp_sink(i2s);

void setup() {
    Serial1.begin(9600, SERIAL_8N1, RX1PIN, TX1PIN);

    Serial.begin(115200);
    Serial.println("START");
    i2s.setPins(I2S_SCK, I2S_WS, I2S_SDOUT);
    if (!i2s.begin(I2S_MODE_STD, 44100, I2S_DATA_BIT_WIDTH_16BIT, I2S_SLOT_MODE_STEREO, I2S_STD_SLOT_BOTH)) {
      Serial.println("Failed to initialize I2S!");
      while (1); // do nothing
    }

    Serial.println("START BT");
    a2dp_sink.start("Picoclock");
}

void loop() {
  //delay(20000);
  while(Serial1.available()) {
    delay(50);
    String in = Serial1.readString();
    in.trim();
    if (in.substring(0, 5) == "START") {
      Serial.println("Received:"+in);
      String bt_name = in.substring(6, in.length());
      Serial.println("Received cut:"+bt_name);
      Serial.println("Starting...");
      a2dp_sink.start(bt_name.c_str());
      Serial1.println("OK");
    } else if (in == "END") {
      Serial.println("Ending...");
      a2dp_sink.end();
      Serial1.println("OK");
    } else if (in == "STATUS") {
      String peer_name = a2dp_sink.get_peer_name();
      Serial.println("Return status:"+peer_name);
      Serial1.println(peer_name);
    } else {
      Serial.println("Received:"+in);
      Serial1.println("UNKNOWN");
    }
  }
}

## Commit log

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2024-06-16 add frontpanel PCB, update back PCB
    [case.stl, frontpanel.kicad_pcb, frontpanel.kicad_sch]
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2024-07-27 [pcb] fix epaper hat position, fix GPIO, add labels
    [picoclock.kicad_pcb, picoclock.kicad_sch]
2024-07-27 [pcb] add PWR from epaper hat
    [picoclock.kicad_pcb, picoclock.kicad_sch]
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2024-07-30 [pcb] update frontpanel (mostly, leds)
    [frontpanel.kicad_pcb, frontpanel.kicad_sch]
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2024-08-03 [pcb] fix frontpanel pcb LEDs + connexion to main pcb
    [frontpanel.kicad_pcb, frontpanel.kicad_sch, picoclock.kicad_pcb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]
2024-08-11 [pcb] add capybara logo
    [frontpanel.kicad_pcb]
2024-08-11 [fw] add mcp9808 temperature lib, beter handling of wifi connexion failure
    [main.c, ost_hal.h, ui_task.c]
2024-08-11 [fw] add pcf8563 library + use it
    No longer connect to wifi at every boot to
    get the date/time: need to add some logic to
    periodically check
    [main.c, ui_task.c]
2024-08-11 [fw] do not partial refresh on clear + fix left btn
    [ui_task.c]
2024-08-15 [pcb] use optocoupler in frontpanel
    [frontpanel.kicad_pcb, frontpanel.kicad_sch]
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2024-08-17 [fw] fixes/improvements here and there
    [ost_hal.h, ui_task.c]
2024-08-17 [fw] fix small bugs
    [ui_task.c]
2024-08-17 [3d] add button (needs to adjust dimensions)
    [button.scad]
2024-08-18 [pcb] add PWM out
    [picoclock.kicad_pcb, picoclock.kicad_sch]
2024-08-23 [3d] increase btn slot size
    [button-2.3.stl, button.scad]
2024-08-25 [case] fix usb position, add internal support
    [case.scad, case_v2.stl, common.scad]
2024-08-25 [pcb] fix PCM5100 layout, AVDD, improvements
    [picoclock.kicad_pcb, picoclock.kicad_sch]
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2024-09-01 [pcb] add sdcard: had to move PCM5100, other
    [picoclock.kicad_pcb, picoclock.kicad_sch]
2024-09-01 [3d] button: 2.4 and 2.5 sizes ok
    [button.scad]
2024-09-01 [build] move files to library/, add missing files
    [ui_task.c]
2024-09-01 [fw] handle multiple alarms (get/store in flash) + fixes
    [main.c, ost_hal.h, pwm_sound.c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]
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2024-09-02 [pcb] new GPIO arrangement
    [frontpanel.kicad_sch, picoclock.kicad_pcb, picoclock.kicad_sch]
2024-09-08 [pcb] add sdcard, audio amplifier
    [picoclock.kicad_pcb, picoclock.kicad_sch]
2024-09-29 [pcb] add epaper driver board
    [epaper-driver.kicad_pcb, epaper-driver.kicad_sch]
2024-09-29 [pcb] update schematic for epaper board
    [epaper-driver.kicad_sch]
2024-10-02 [3d] small changes to case
    [button-2.3.stl, button-2.4.stl, button-2.5.stl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]
2024-10-02 [pcb] update/fixes for #prod2
    [picoclock.kicad_pcb, picoclock.kicad_sch]
2024-10-05 [3d] add stronger support following jlcpcb review
    [case.scad, case.stl, common.scad]
2024-10-05 [pcb] CYW43439 module board
    Missing antenna, needs tons of review
    [CYW43439.kicad_pcb, CYW43439.kicad_sch]
2024-10-23 [pcb] epaper-driver: mostly silkscreen size changes
    [epaper-driver.kicad_pcb]
2024-10-25 [pcb] move rev2 into dedicated folder + start new rev
    [CYW43439.kicad_pcb, CYW43439.kicad_sch, epaper-driver.kicad_sch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]
2024-10-26 [pcb] audio circuit fixes
    [picoclock.kicad_pcb, picoclock.kicad_sch]
2024-10-27 [pcb] fpc screen connector at the right place
    [picoclock.kicad_pcb, picoclock.kicad_sch]
2024-10-27 [fw] audio rework: use digital pot (mcp4652), enable i2s with dma/pio
    [main.c, ost_hal.h, ui_task.c]
2024-11-13 [pcb] CYW43439: add 4 layers version
    [CYW43439.kicad_pcb, CYW43439.kicad_sch]
2024-11-13 [pcb] rename 2 layers version to CYW43439-2L
    [CYW43439.kicad_pcb, CYW43439.kicad_sch]
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2024-12-03 [pcb] fixes for mcp23009 (bad footprint)
    [picoclock.kicad_pcb, picoclock.kicad_sch]
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2024-12-15 [mcp23009] add more functions, fixes for PCBv2
    [main.c, main.h, ui_task.c]
2024-12-15 [pcb] add pullup resistor for MCP23009
    [picoclock.kicad_pcb, picoclock.kicad_sch]
2024-12-24 [3d] add front screen holder (still wip)
    [front.scad, front.stl]
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2025-01-18 [3d] update front screen holder
    [front.scad, front.stl]
2025-01-18 [pcb] update 4 layer wifi test board
    [CYW43439.kicad_pcb, positions.csv]
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2025-01-18 [pcb] move battery holder, other small tweaks
    [picoclock.kicad_pcb, picoclock.kicad_sch]
2025-02-13 [fw] add 4651 support, tweaks&fixes
    [main.c, main.h, ui_task.c]
2025-02-15 [fw] big update: config support, split code
    [picoclock.kicad_sch]
2025-02-24 reliability: avoid crash if mcp23009 is not found
    [main.c]
2025-03-05 [fw] do not crash on mp23009 not available
    [main.c, ui_task.c]
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2025-03-08 [pcb] mono audio, combined sdcard footprint
    [epaper-driver.kicad_sch, frontpanel.kicad_pcb, frontpanel.kicad_sch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]
2025-03-15 [3d] revamp of screen support (front), add panel (wip), fixes on main case
    [case.scad, common.scad, front.scad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]
2025-03-19 [3d] first usable release of panel, add button stl
    [button.stl, panel.scad, panel.stl]
2025-03-20 [3d] fix panel
    [common.scad, front.scad, panel.scad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]
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2025-05-18 [pcb] move symbols into common lib, add pogo pins on pico
    [picoclock.kicad_pcb, picoclock.kicad_sch]
2025-05-18 [fw] support for "V4B" screen + add reboot everyday with watchdog
    [main.c, main.h, ui_task.c]
2025-06-08 [case] add USB-A port
    [case.scad, common.scad]
2025-06-08 [pcb] adjust pcb outline
    [picoclock.kicad_pcb]
2025-08-31 [CYW43439] fix VDDBAT/LDO_IN short circuited, others
    [CYW43439-B_Cu.gbr, CYW43439-B_Mask.gbr, CYW43439-B_Paste.gbr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]
2025-10-19 [pcb] add new 'mini' version with integrated RP2350 + ESP32
    [CYW43439-B_Cu.gbr, CYW43439-B_Mask.gbr, CYW43439-B_Paste.gbr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]
2025-11-01 [pcb-mini] add ESP32, RM2, route most things
    [RM2.kicad_sch, esp32.kicad_sch, picoclock.kicad_pcb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]
2025-11-01 [pcb-mini] fix warnings/errors
    [esp32.kicad_sch, picoclock.kicad_pcb, picoclock.kicad_sch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]
2025-11-09 [3d] add mini case
    [case.scad, picoclock.kicad_pcb]
2025-11-09 [3d] add screen holder for mini case
    [case.scad, common.scad, screen_holder.scad]
2025-11-11 [mini] add pin for screen holder in pcb + 3d
    [case.scad, common.scad, picoclock.kicad_pcb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]
2025-11-11 [3d] add stl for front/screenholder/pcb
    [case-front.stl, case-pcb.stl, case-screenholder.stl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]
2025-11-14 [3d] fix io ports, add back case
    [case.scad, common.scad]
2025-11-15 [3d] mini: finish back, lots of others improvements, generate prod v2
    [case-back.stl, case-front.stl, case-screenholder.stl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]
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2025-11-16 [mini] fix I/O positions, add jack in case
    [case-back.stl, case-front.stl, case.scad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]
2025-11-16 [pcb] mini: audio shut internal speaker when hack is connected
    [picoclock.kicad_pcb, picoclock.kicad_sch]
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2025-11-20 [3d] mini: improvements
    - [done] increase screw hole size
    - [done] increase depth for back case bolts
    - [done] add hole under for speaker screws
    - [done] move speaker closer to wall by 4mm
    [case.scad, common.scad]
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2025-11-23 [3d] mini: reduce thickness to 1.5, decrease bolt hole diameter
    [case-back.stl, case-front.stl, case.scad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]
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2025-11-23 [pcb] mini: many silkscreen fixes
    [picoclock.kicad_pcb, uC.kicad_sch]
2025-11-25 [3d] mini: fix screw pos
    [case-back.stl, case.scad]
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2025-11-30 [pcb] mini: fix I2S switch footprint, many small tweaks
    [picoclock.kicad_pcb, picoclock.kicad_sch]
2025-11-30 [3d] mini: fix front, add prod release v6
    [case-back.stl, case-front.stl, case.scad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]
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2025-12-06 [pcb] mini: add debug port, improve/fix traces
    [picoclock.kicad_pcb, picoclock.kicad_sch, uC.kicad_sch]
2025-12-07 [pcb] mini: cleanup schematic, fix 3.3v zone
    [picoclock.kicad_pcb, picoclock.kicad_sch]
2025-12-13 [pcb] mini: add/fix LCSC refs
    [RM2.kicad_sch, epaper-driver.kicad_sch, esp32.kicad_sch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]
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2026-01-09 [fw] fixes for pcb mini
    [main.c]
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2026-01-14 [3d-mini] wip on fixing joint between back and front
    [case.scad, common.scad]
2026-01-14 [case] fix pcb support
    [case.scad]
2026-01-14 [fw] fix alarm on mini pcb
    [main.c, ui_task.c]
2026-01-14 [fw] fix or remove comments
    [main.c]
2026-01-15 [3d] mini: fix back+front + add v7 prod
    [case-back.stl, case-front.stl, case.scad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]
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2026-01-16 [pcb] mini: fix audio connector, resistor on 74LS157
    [picoclock.kicad_pcb, picoclock.kicad_sch, uC.kicad_sch]
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2026-01-17 [3d] mini: fix sdcard+usb-c depth, deeper screw holes
    [case-back.stl, case.scad, common.scad]
2026-01-17 [pcb] mini: RGB led footprint fixes
    [picoclock.kicad_pcb, picoclock.kicad_sch]
2026-01-20 [fw] fix wifi crash on core0, reduce calls to pcf8563, cleanup
    [main.c, main.h, ui_task.c]
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2026-01-21 [3d] mini small adjustment + remove large speaker
    [case-back.stl, case.scad, common.scad]
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2026-01-30 [pcb] mini: show silkscreen of ens160 dc-dc converter
    [picoclock.kicad_pcb]
2026-01-31 [pcb] mini: RTC: add diods, wire INT. fix 74LS chip footprint
    [picoclock.kicad_pcb, picoclock.kicad_sch, uC.kicad_sch]
2026-02-01 [fw] fix red led, send metrics to server
    [main.c, main.h, ui_task.c]
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2026-02-08 [pcb] mini: move boot btn, add silkscreen, add con for ESP32 UART
    [esp32.kicad_sch, picoclock.kicad_pcb, uC.kicad_sch]
2026-02-12 [fw] fixes for alarm screen, remove logs
    [main.c, ui_task.c]
2026-02-12 [fw] tentative wifi fix, clean logs
    [main.c]
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2026-02-15 [pcb] mini: add SHT40 + senseair S88 connectors
    [picoclock.kicad_pcb, picoclock.kicad_sch]
2026-02-17 [3d] mini: put speaker on bottom, add air vents
    [case-back.stl, case.scad, common.scad]
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2026-03-04 [3d] mini: add btn for short pusher, improve normal one
    [button.stl, button_shortbase.scad, button_shortbase.stl]
2026-03-04 [pcb] mini: add decoupling caps, improve power path of screen
    [picoclock.kicad_pcb, picoclock.kicad_sch, uC.kicad_sch]
2026-03-08 [fw] replace i2c_read_blocking() with i2c_read_timeout_us(), add logs
    [main.c, main.h]
2026-03-08 [fw] disable gpio to detect sd card, not working
    [main.c]
2026-03-10 [3d] mini: improve shortbase btn
    [button_shortbase.scad, button_shortbase.stl]
2026-03-14 [pcb] fix SD card detection (add pullup) + improve footprint
    [picoclock.kicad_pcb, picoclock.kicad_sch]
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2026-04-06 [fw] quick fix for file dl, start OTA work (not working)
    [main.c, main.h, sdcard.c]
2026-04-08 [fw] experiment with fw update (not working)
    [main.c, main.h]
2026-04-11 [fw] try to improve reboot
    [main.c, main.h]
2026-04-12 [stcc] fix buffer length to account for crc
    [main.h]
2026-04-13 [fw] fix fs mount, add support for long press
    [main.c, main.h, ui_task.c]
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2026-04-28 [case] replace long holes by screw inserts
    [case.scad, case.stl]
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2026-05-15 [3d] screen holder: add borders, increase guideline size
    [common.scad, screen_holder.scad, screen_holder.stl]
2026-05-18 [3d] fix screenholder borders (v12)
    [screen_holder.scad, screen_holder.stl]
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2026-05-20 [small fixes, v13-3
    [screen_holder-3.stl, screen_holder.scad]
2026-06-02 [fw] tentative fix (prob. again not working)
    [main.c]
2026-06-06 Revert "[fw] tentative fix (prob. again not working)"
    This reverts commit 2324c3e6f716d66b9156ddabed7a2ffb54288037.
    [main.c]
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
